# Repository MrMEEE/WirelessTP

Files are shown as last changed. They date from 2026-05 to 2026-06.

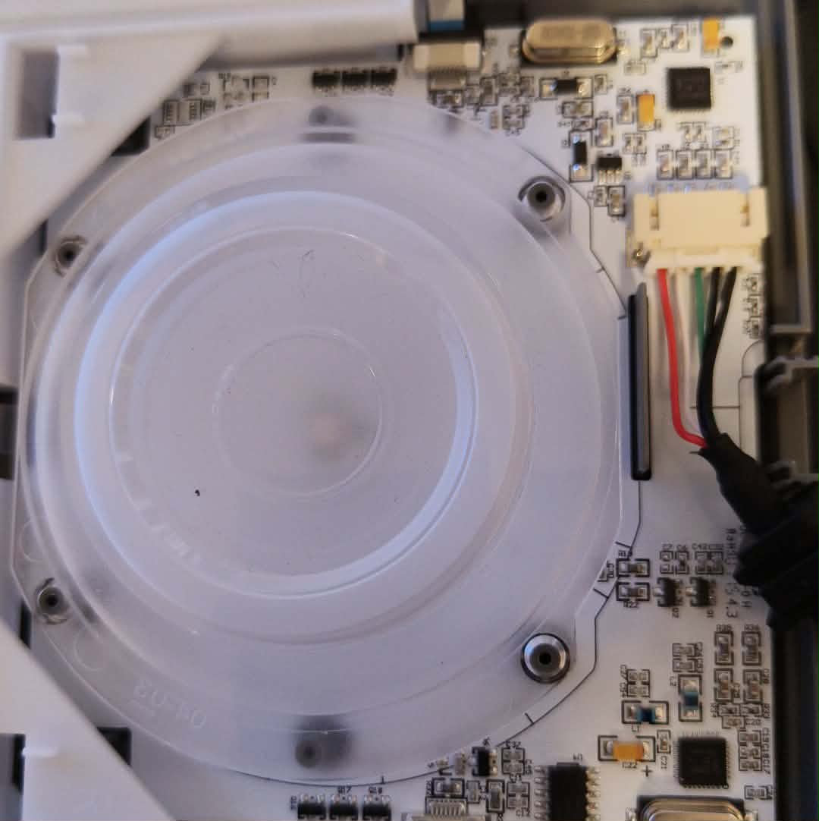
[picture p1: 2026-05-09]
pcb/pics/overview.jpeg

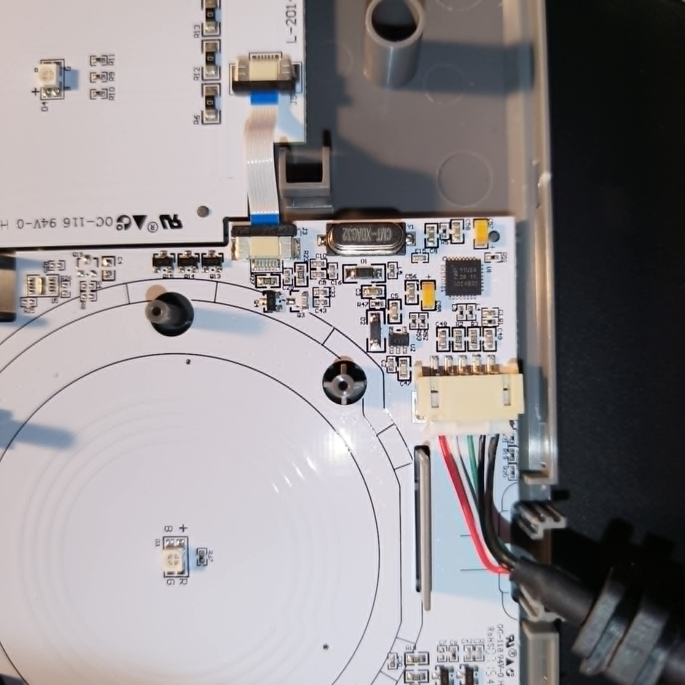
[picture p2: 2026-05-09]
pcb/pics/left.jpeg

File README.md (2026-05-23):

# Wireless LEGO Dimensions Toy Pad Bridge (RP2040 + ESP32 + ESP32)

This repository is a starter for a 3-board architecture:

- Console dongle USB side: Seeed XIAO RP2040
- Console dongle radio side: ESP32 (classic ESP-WROOM-32 is fine)
- Pad side: ESP32

## Why this split

- RP2040 handles strict USB device timing and Toy Pad emulation.
- Console ESP32 hosts a direct open SoftAP and forwards paired pad events over UART to RP2040.
- Pad ESP32 handles tag sensing / virtual events and sends events over Wi-Fi.
- Pad ESP32 includes local setup AP + web portal for first-time provisioning.

This keeps USB timing isolated from Wi-Fi jitter.

## Current status

- Shared packet format (`shared/include/link_protocol.h`) created.
- Console ESP32 starter firmware added (`firmware/console-esp32/src/main.cpp`).
- Console RP2040 starter firmware added (`firmware/console-rp2040/src/main.cpp`).
- Pad ESP32 starter firmware added (`firmware/pad-esp32/src/main.cpp`).
- First protocol document added (`protocol/toypad_link_v1.md`).
- Framed transport with CRC + ACK + heartbeat is wired in all three targets.
- Bring-up checklist added (`docs/bringup-checklist.md`).
- Direct open-AP pairing flow is implemented (no external router required, no serial pair code entry).
- USB protocol findings + RP2040 checklist documented (`docs/usb-protocol-findings-and-rp2040-checklist.md`).
- Xbox 360 donor-auth integration strategy documented (`docs/xbox360-auth-donor-strategy.md`).

## Hardware wiring (console side)

Use UART between console ESP32 and XIAO RP2040:

- ESP32 TX -> RP2040 RX
- ESP32 RX <- RP2040 TX
- ESP32 GND <-> RP2040 GND

Use 3.3 V logic only.

## Build approach

These are framework starter files (not yet board-package complete project files).

For VS Code + PlatformIO IDE, you can now open the repository root directly because it contains a top-level `platformio.ini` that exposes all firmware targets.

You can also open the workspace file at the repo root:

`WirelessTP.code-workspace`

That workspace adds each firmware target as its own VS Code folder so the PlatformIO extension can also show them as separate projects in one window.

You can use either:

1. Arduino IDE per board, or
2. PlatformIO with one env per target.

For the RP2040 there is a single unified environment — profile selection happens at runtime
via a physical toggle switch on the board.

The root-level PlatformIO environments are:

1. `console_esp32`
2. `pad_esp32`
3. `console_rp2040`

## Next milestones

1. Replace RP2040 placeholder with full TinyUSB Toy Pad descriptor + endpoint handlers.
2. Implement deterministic state map for the 3 pad zones and 7 minifig slots.
3. Implement PS-profile USB command parser/checksum path (`0xb0`, `0xc0`, `0xc8`, `0xc2`, `0xc3`).
4. Add NFC reader integration on pad-side ESP32 (or keep virtual events first).
5. Add LED command flow from console game -> RP2040 -> console ESP32 -> pad ESP32.

## Platform support plan

- PlayStation Toy Pad is the primary target for first functional milestone.
- Xbox 360 support is planned next; expect additional compatibility/auth investigation.
- For Xbox 360, start with donor-board auth reuse before attempting chip-level transplant (`docs/xbox360-auth-donor-strategy.md`).
- For jailbroken Xbox 360 setups (JTAG/RGH), an optional modern-controller workaround path is also documented (`docs/xbox360-auth-donor-strategy.md`).
- RP2040 firmware is a single unified build (`console_rp2040`); PS3/Xbox 360 profile is selected at runtime via a physical toggle switch.

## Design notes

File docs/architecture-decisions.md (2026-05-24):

# Architecture Decisions

## Why the console side uses two boards (RP2040 + ESP32)

**Question considered:** Can a single ESP32-S2 Mini replace both the console-rp2040
and console-esp32, eliminating the UART link and the extra board?

**Short answer:** Technically possible, but deliberately not done.

### What each board currently does

| Board | Role |
|---|---|
| XIAO RP2040 | USB HID *device* to game console — emulates the toy pad, handles TEA auth (B1/B3), responds to tag/LED commands |
| Console ESP32 | WiFi AP, web UI, TCP server for pad-esp32, game state (slots/toybox), forwards LP frames to/from RP2040 |

### Why the ESP32-S2 is not a drop-in replacement

1. **USB timing isolation.**
   The RP2040 has no WiFi and a bare-metal FreeRTOS-free loop. Its `loop()` calls
   `TinyUSBDevice.task()` twice per iteration specifically to chain B0 replies within
   one 1 ms USB poll window. On the ESP32-S2, FreeRTOS WiFi tasks (lwIP, beacon
   handling, TCP stack) run on the same or adjacent cores and can introduce multi-ms
   jitter. The B1/B3 TEA auth and the B0 reply timing are sensitive enough that this
   can cause the game console to fail HID enumeration, particularly on real hardware
   (less visible on RPCS3).

2. **RP2040-specific linker tricks cannot be trivially ported.**
   The RP2040 firmware patches the USB configuration descriptor using GCC `--wrap`
   linker symbols (`__wrap_TinyUSB_Device_Init`,
   `__wrap_tud_descriptor_configuration_cb`). These intercept Arduino TinyUSB
   internals at link time. The ESP32-S2 uses the ESP-IDF toolchain; equivalent
   patching would require rewriting these hooks against IDF's `tusb_config` and
   custom descriptor callbacks — a non-trivial porting effort with different testing
   requirements.

3. **`tud_hid_report_complete_cb` chaining.**
   The firmware queues the B0 USB reply inside the HID report-complete callback to
   avoid waiting a full loop cycle. This interrupt-context chaining works reliably on
   RP2040 TinyUSB HAL. Its behaviour on ESP32-S2 TinyUSB (which dispatches USB
   events differently under IDF) has not been validated.

4. **USB serial debug lost.**
   Once the S2's USB OTG port is owned by the game console as a HID device, USB
   serial is gone. All debug output would require a UART adapter on GPIO 43/44.
   On the RP2040 this is a non-issue because the board has a second USB interface
   (XIAO exposes CDC ACM separately from the HID interface).

### Summary

The two-board split exists because the RP2040 provides bare-metal USB timing that
the ESP32-S2 cannot guarantee while simultaneously running a WiFi stack. Merging
them would trade a clean UART interface for a complex, risk-laden port with no clear
gain in the current scope. If timing requirements relax or the protocol is changed
to tolerate jitter, this decision should be revisited.

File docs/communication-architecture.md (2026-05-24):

# WirelessTP Communication Architecture

## System topology

```
Physical Toy Pad (USB HID, VID:PID 0e6f:0241)
        │
        │ USB OTG – host mode (pad-esp32 is host)
        │ 32-byte interrupt IN/OUT reports @ 1ms poll
        ▼
┌────────────────────────┐
│  ESP32-S2 Mini         │  pad-esp32
│  USB host + WiFi STA   │
│  GPIO43=TX  GPIO44=RX  │  (UART for debug only – no LP traffic)
└────────────────────────┘
        │
        │ WiFi – STA joins console softAP
        │ TCP socket, port 25100, LP frames (Link A)
        │ WiFi.setSleep(false), setNoDelay(true)
        ▼
┌────────────────────────┐
│  ESP32 (dual-core)     │  console-esp32
│  WiFi softAP           │  IP 192.168.44.1 (DHCP)
│  GPIO16=RX  GPIO17=TX  │  UART to RP2040 (Serial2, 115 200 baud)
│  USB CDC for debug     │
└────────────────────────┘
        │
        │ UART 115 200 baud, LP frames (Link B)
        │ RP2040 Serial1 D6=TX D7=RX ↔ ESP32 Serial2 GPIO17=TX GPIO16=RX
        ▼
┌────────────────────────┐
│  XIAO RP2040           │  console-rp2040
│  USB HID device        │  emulates Toy Pad
│  (bare-metal loop)     │
└────────────────────────┘
        │
        │ USB HID, VID 0e6f PID 0241 ("LEGO READER V2.10")
        │ 32-byte interrupt IN/OUT reports @ 1ms poll
        ▼
     PS3 / RPCS3 (game)
```

---

## Link A — pad-esp32 ↔ console-esp32 (WiFi TCP)

### Transport

| Property | Value |
|---|---|
| Transport | TCP (not UDP — the original spec was provisional) |
| Console port | 25100 |
| Console IP | 192.168.44.1 (softAP gateway) |
| WiFi AP SSID | `ToyPadConsole-{CHIPID_24LSB_HEX}` |
| AP security | Open (no password) |
| Modem sleep | Disabled: `WiFi.setSleep(false)` on pad |
| Nagle | Disabled: `setNoDelay(true)` on both ends after connect |
| Frame format | LP (see protocol spec) |

### Pad connection state machine

```
CONN_SEARCHING
  ├─ Blink LED yellow (400 ms on/off)
  ├─ TCP connect attempt every kRetryMs=50ms (after disconnect)
  ├─ Send HELLO every kHelloMs=2000ms once connected
  └─► CONN_BLINK_OK   on PAIR_SET received
      └─► CONN_PAIRED  after 3× green blink (≈1200 ms)
CONN_PAIRED
  ├─ Send HELLO every kHeartbeatMs=5000ms (trackAck=true)
  ├─ Re-sync state every kStateSyncMs=1000ms
  ├─ Send pad-dbg (WiFi RSSI/status) every 1000ms
  ├─► CONN_SEARCHING  if !client.connected()  [fast path, no blink]
  └─► CONN_BLINK_FAIL if lastPeerMs > kLostMs=30000ms
CONN_BLINK_FAIL
  ├─ Blink LED red 3×
  └─► CONN_SEARCHING
```

### Pairing sequence (first connection)

```
pad-esp32                            console-esp32
    │                                     │
    │── TCP connect ──────────────────────►│ (accept, setNoDelay, lp_stream_reset)
    │                                     │
    │── HELLO [0xa1]  (trackAck=true) ───►│ isValidPadHello: length=1 → enrollment
    │                                     │ ensureSecret() → generates random 32-bit secret
    │◄── PAIR_SET [secret_u32_le] ────────│
    │                                     │
    │── ACK [pair_set_seq] ───────────────►│
    │  (pending.active=false, paired=true) │
    │  saveSharedSecret()                  │
    │  connState = CONN_BLINK_OK           │
```

### Subsequent connections (known pad)

```
pad-esp32                            console-esp32
    │                                     │
    │── TCP connect ──────────────────────►│
    │── HELLO [0xa1, secret_u32_le] ──────►│ secret matches → padPaired=true
    │◄── PAIR_SET [same secret] ───────────│
    │── ACK ──────────────────────────────►│
```

### Frame flows while paired

| Direction | Frame | Sender action | Receiver action |
|---|---|---|---|
| pad→console | HELLO | every 5 s heartbeat, trackAck=true | ACK, no forward to RP2040 |
| pad→console | TAG_SET | figure placed (physical or virtual), trackAck=true for real events | ACK, forward to RP2040 UART |
| pad→console | TAG_CLEAR | figure removed, trackAck=true | ACK, forward to RP2040 UART |
| pad→console | ACK | response to console LED_CMD | forward to RP2040 UART (harmless; RP2040 does `break`) |
| pad→console | DEBUG (0x40) | WiFi diagnostics every 1 s | print `[pad-dbg]`, **not** forwarded to RP2040 |
| console→pad | LED_CMD | state sync every 1 s (from `lightZones[]`) | ACK, apply colour to physical pad |
| console→pad | PAIR_SET | on pairing | pad saves secret, enters BLINK_OK |

### Pad periodic state sync (every kStateSyncMs=1000ms in CONN_PAIRED)

- Sends TAG_SET for each occupied physical USB zone (zones 0-2 → slots 1-3), trackAck=false
- Sends TAG_SET for each occupied virtual slot (4-7, or 1-7 in no-USB builds), trackAck=false
- Does **not** send TAG_CLEAR for empty slots (avoids queue floods)

### Pad diagnostic frame (LP_MSG_DEBUG)

Sent every 1 second while in CONN_PAIRED:

```
payload: "rssi=-47 wf=3"   (rssi = WiFi.RSSI(), wf = WiFi.status())
```

Console prints as `[pad-dbg] rssi=-47 wf=3` to USB serial. Never forwarded to RP2040.

---

## Link B — console-esp32 ↔ console-rp2040 (UART)

### Transport

| Property | Value |
|---|---|
| Physical | UART, 115 200 baud, 8N1 |
| Console ESP32 | Serial2, GPIO16=RX / GPIO17=TX |
| RP2040 | Serial1, D6=TX / D7=RX |
| Frame format | LP (same protocol as Link A) |

### HELLO heartbeats (bidirectional, independent timers)

| Sender | Payload | Interval | Purpose |
|---|---|---|---|
| console-esp32 → RP2040 | `[0xb1]` | 3 000 ms | console alive signal |
| RP2040 → console-esp32 | `[0x02]` | 4 000 ms | RP2040 alive signal |

Both sides ACK received HELLOs; neither side takes action on missed heartbeats (no timeout logic implemented).

### Frame forwarding rules (console-esp32)

**From pad TCP → RP2040 UART:**

| Frame type | Action |
|---|---|
| HELLO | Drop (pad↔console specific) |
| PAIR_SET | Drop (pad↔console specific) |
| DEBUG (0x40) | Print `[pad-dbg]`, drop — NOT forwarded |
| ACK (0x7F) | Currently forwarded (RP2040 ignores with `case LP_MSG_ACK: break`) |
| TAG_SET, TAG_CLEAR | Re-encode with original seq and write to Serial2 |

**From RP2040 UART → pad TCP:**

| Frame type | Action |
|---|---|
| LED_CMD | Forward to pad TCP via `sendFrameTcp()` |
| HELLO, ACK, DEBUG, all others | Drop |

**ACK sending:**
- All non-ACK frames from pad TCP → ACK sent back to pad TCP
- All non-ACK / non-DEBUG frames from RP2040 UART → ACK sent back to RP2040 UART

### Console state sync (every kStateSyncMs=1000ms)

- TAG_SET to RP2040 UART for each occupied slot in `padSlots[]`
- LED_CMD to pad TCP for each zone in `lightZones[]` (only if `padPaired`)
- `padSlots[]` is **not** cleared when the pad disconnects

### RP2040 toy event queue

- `enqueueToyTagEvent()` queues a 32-byte USB IN packet (placed/removed event)
- `serviceToyInQueue()` drains the queue each loop: peek → `usb_hid.sendReport()` → pop on success
- If `!TinyUSBDevice.mounted()`: entire queue is discarded (`memset(&toyInQueue, 0, ...)`) to prevent stale events accumulating

---

## USB HID protocol (RP2040 ↔ game)

### Descriptors

```
VID:PID      0x0e6f : 0x0241
Manufacturer "PDP LIMITED. "
Product      "LEGO READER V2.10"
Serial       "P.D.P.000000"
Class        HID (vendor-specific usage page 0xff00)
bmAttributes 0x80  (bus powered)
bMaxPower    250   (500 mA)
Report size  32 bytes IN + 32 bytes OUT @ 1 ms poll
bcdHID       0x0100 (patched from TinyUSB default 0x0110)
EP packet    32 bytes IN / 32 bytes OUT (patched from 64)
```

### Host→Pad OUT packets (command)

```
[0] 0x55  magic
[1] len   data bytes following (= 1 + argsLen + 1 for counter+args+checksum)
[2] cmd
[3] counter
[4..4+argsLen-1] args
[4+argsLen] checksum = sum(bytes[0..4+argsLen-1]) & 0xff
[...] zero padding to 32 bytes
```

### Pad→Host IN packets

**Command reply:**
```
[0] 0x55  magic
[1] len   (= 1 + payloadLen)
[2] counter (echoes command counter)
[3..3+payloadLen-1] reply payload
[3+payloadLen] checksum
[...] zeros
```

**Tag event:**
```
[0]  0x56  magic
[1]  0x0b  payload length
[2]  pad   (1=center, 2=left, 3=right)
[3]  0x00  reserved
[4]  figIndex (= slot number 1-7, unique per toy)
[5]  action (0=placed, 1=removed)
[6..12] uid (7 bytes)
[13] checksum
[...] zeros
```

### Commands

| Cmd | Name | Args | Reply payload |
|-----|---|---|---|
| B0 | Init | startup string (observed 16 bytes) | 30-byte capability response |
| B1 | RNG seed | 8 bytes (TEA-encrypted seed+confirmation) | 8 bytes (TEA-encrypted confirmation) |
| B3 | RNG challenge | 8 bytes (TEA-encrypted confirmation) | 8 bytes (TEA-encrypted nextRand+confirmation) |
| C0 | LED immediate | pad(1-3/0=all), r, g, b | empty |
| C2 | LED fade | pad, pulseTime, pulseCount, r, g, b | empty |
| C3 | LED flash | pad, onLen, offLen, pulseCount, r, g, b | empty |
| C6 | LED tri-fade | 3×6 bytes (center, left, right): effect, dur, cnt, r, g, b | empty |
| C8 | LED tri-set | 3×4 bytes (center, left, right): enable, r, g, b | empty |
| D2 | NFC page read | figIndex, startPage → 4 pages (16 bytes) | 0x00 + 16 bytes |
| D3 | NFC page write | figIndex, page, 4 bytes | empty |
| D4 | NFC extended | figIndex, page, ... | varies |

### B1/B3 cryptography

Algorithm matches RPCS3 `Dimensions.cpp`:
- TEA (Tiny Encryption Algorithm), 32 rounds, key = `kCommandKey` (16 bytes hard-coded)
- B1: decrypt challenge → extract seed → init Bob Jenkins PRNG → encrypt confirmation
- B3: decrypt challenge → `rngGetNext()` → encrypt [nextRand LE | conf BE]

### NFC figure data synthesis (D2 replies)

Toy ID is 32 bits: `uid[0..3]` (LE) for physical figures, or the virtual `toyId` for emulated ones.

UID is synthesised as:
```
uid[0..3] = toyId (LE)
uid[4]    = 0xa5
uid[5]    = slot (1-7)   ← makes each slot's UID unique
uid[6]    = toyId ^ 0x5a
```

Pages 0, 1, 2 contain the NTAG213 UID/BCC structure.
Pages 36-37 contain the TEA-encrypted figure identity, using a per-UID figure key
generated by `generateFigureKey()` (matching RPCS3's `generate_figure_key`).

---

## Zone / slot / pad-index convention

Three coordinate systems exist; mappings are defined in firmware:

| Name | Values | Used by |
|---|---|---|
| LP zone | 0=center, 1=left, 2=right | Link A+B LP frames |
| Toy Pad pad-index | 1=center, 2=left, 3=right | USB HID C0/C2/C3 commands |
| Web UI slot | 1-7 | console-esp32 web API, LP TAG_SET/CLEAR payload byte 0 |
| figIndex | 1-7 (= slot) | USB IN tag events, D2 args |

**Slot-to-zone mapping (mirrored in ESP32 and RP2040):**

| Slot | LP zone | Pad-index |
|---|---|---|
| 1 | 1 (left) | 2 |
| 2 | 0 (center) | 1 |
| 3 | 2 (right) | 3 |
| 4 | 1 (left) | 2 |
| 5 | 1 (left) | 2 |
| 6 | 2 (right) | 3 |
| 7 | 2 (right) | 3 |

**Physical USB zone → LP slot (pad-esp32, kZoneToSlot):**

| USB zone (from toypad IN report) | LP zone | Slot |
|---|---|---|
| zone byte 1 (center) | 0 | 2 |
| zone byte 2 (left) | 1 | 1 |
| zone byte 3 (right) | 2 | 3 |

---

## Timing reference

| Constant | Value | Location | Purpose |
|---|---|---|---|
| `kHelloMs` | 2 000 ms | pad-esp32 | HELLO rate while searching |
| `kPairTimeoutMs` | 15 000 ms | pad-esp32 | Give up pairing → blink fail |
| `kHeartbeatMs` | 5 000 ms | pad-esp32 | HELLO rate while paired |
| `kLostMs` | 30 000 ms | pad-esp32 | Console silent → blink fail |
| `kStateSyncMs` | 1 000 ms | pad-esp32 | State re-broadcast interval |
| `kRetryMs` | 50 ms | pad-esp32 | ACK retry interval |
| `kMaxRetries` | 3 | pad-esp32 | Max retry count before drop |
| `kBlinkOnMs/OffMs` | 200/200 ms | pad-esp32 | OK/fail blink timing |
| `kHelloMs` | 3 000 ms | console-esp32 | Console→RP2040 heartbeat rate |
| `kStateSyncMs` | 1 000 ms | console-esp32 | State re-broadcast to RP2040+pad |
| `kHelloMs` | 4 000 ms | console-rp2040 | RP2040→console heartbeat rate |

---

## Reliability model

### Pad-side (Link A outbound)

`sendFrame(type, payload, len, trackAck)`:
- `trackAck=true`: stores frame in `pending`; retried every `kRetryMs=50ms` up to `kMaxRetries=3` from the CONN_PAIRED loop
- `trackAck=false`: fire-and-forget

Frames sent with `trackAck=true`:
- HELLO (heartbeat and searching)
- TAG_SET / TAG_CLEAR from physical USB host events
- TAG_SET / TAG_CLEAR from virtual toy menu

Frames sent `trackAck=false` (fire-and-forget):
- State sync TAG_SET (periodic re-broadcast — retrying is redundant with periodic sync)
- ACK responses
- DEBUG diagnostics

### Console-side (Links A+B inbound)

Every received non-ACK frame generates an ACK back to the sender (pad TCP or RP2040 UART).
The console itself does not have a retry mechanism for outbound frames — it relies on the
periodic state sync to recover from dropped LED_CMDs and TAG_SETs.

---

## Provisioning flow (pad-esp32 first run)

1. Pad has no WiFi credentials in NVS → enters provisioning AP mode
2. Provisioning AP SSID: `ToyPad-Setup`, password: `toypadsetup`
3. DNS catches all hostnames (captive portal pattern)
4. User visits `http://192.168.x.x/` → selects console AP from scan list → submits
5. Credentials saved to NVS (`toypad` namespace, keys `ssid`/`pass`)
6. Reboot → connects to console AP → proceeds to LP pairing

Factory reset: hold BOOT button (GPIO 0) for 3 s → NVS clear + reboot.

---

## Debug interfaces

### pad-esp32

| Interface | Details |
|---|---|
| UART debug | GPIO43=TX / GPIO44=RX, 115 200 baud (USB CDC disabled in USB-host builds) |
| Serial menu | Interactive: press any key; commands `s` / `p <slot>` / `r <slot>` / `f <text>` |
| Web UI | `http://<pad-IP>/` — shows state, console IP, WiFi info |
| LED feedback | Yellow=searching, green blink=paired, red blink=fail |
| pad-dbg relay | WiFi RSSI + status relayed to console as LP_MSG_DEBUG every 1 s |

### console-esp32

| Interface | Details |
|---|---|
| USB CDC serial | 115 200 baud; also prints RP2040 debug (`[lp-debug]`) and pad debug (`[pad-dbg]`) |
| Serial commands | `help`, `pi-console on/off` |
| Web UI | `http://192.168.44.1/` — full toy pad management UI (slots, toybox, LED state, catalog) |
| Log prefixes | `[console-esp32]` events, `[led-rx]` LED commands, `[lp-debug]` RP2040 debug, `[pad-dbg]` pad debug |

### console-rp2040

| Interface | Details |
|---|---|
| UART debug | Serial1 shared with LP link (debug output interleaved with LP frames — console-esp32 filters by CRC) |
| LP_MSG_DEBUG | Sent via UART; console-esp32 prints as `[lp-debug]` |
| Stats | `b0 stats rx=%u q=%u tx=%u` printed every 3 000 ms |

---

## Known issues and active investigations

### TCP disconnect every 3-5 seconds (active)

The pad TCP connection drops reliably every few seconds. WiFi is confirmed stable
(wf=3, rssi=-43 to -47 throughout). The `WiFiClient::connected()` implementation
calls `recv(fd, 0, MSG_DONTWAIT)` and returns false only on RST-level errors
(ECONNRESET/EPIPE/EBADF); FIN does not trigger it. The source of the RST is unknown.

Leading hypotheses (in priority order):
1. lwIP internal socket management on the ESP32-S2 — possibly a timer or PCB limit
2. The console forwarding LP_MSG_ACK frames (from pad's LED_CMD ACKs) to RP2040 UART; RP2040 ignores them but the UART traffic is unnecessary
3. The console's `padClient = incoming` path — replacing a connected client when a new TCP SYN arrives (would print "replacing stale" but may happen silently if `padClient.connected()` transiently returns false)

To diagnose: add errno capture in `tcpSendWire()` and a raw `recv()` probe in
the CONN_PAIRED disconnect handler; relay as first pad-dbg of next connection.

### LP_MSG_ACK forwarding to RP2040 (minor)

The console currently forwards pad ACKs (0x7F) to the RP2040 via UART. The RP2040
handles these with `case LP_MSG_ACK: break;` — safe but wasteful. These 3 frames/second
(one per LED_CMD zone) serve no purpose at the RP2040 level and should be filtered.

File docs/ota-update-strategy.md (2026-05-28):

# OTA / Firmware Update Strategy

## Overview

Three SoCs need to be updated when new firmware is released:

| SoC | Role | Link to console-esp32 |
|---|---|---|
| **console-esp32** | WiFi AP, web UI, TCP broker | — (self) |
| **console-rp2040** | USB HID device to PC/RPCS3 | UART (115200 baud, LP protocol) |
| **pad-esp32** | USB host for physical toypad, WiFi station | WiFi TCP (LP protocol, port 25100) |

The goal is a one-click update flow from the console-esp32 web UI that requires no physical button presses on any board.

---

## Per-Chip Strategy

### 1. console-rp2040 — Custom UART DFU (zero-touch)

The console-esp32 streams the new RP2040 firmware directly over the existing UART connection
using a lightweight chunked DFU protocol. The RP2040 stages the image in the upper half of
its 2 MB flash using arduino-pico's `Updater` class, then reboots to apply it. No button
press, no drag-and-drop — fully automatic.

**Why not BOOTSEL?**
When the RP2040 enters BOOTSEL mode it presents a USB mass-storage drive on the **PC**,
not on the UART-connected console-esp32. The plain ESP32 has no USB host hardware, so it
cannot write to that drive. BOOTSEL is not useful for an automated update flow.

**Why arduino-pico `Updater`?**
The EarlePhilhower arduino-pico fork includes an `Updater` class that writes incoming bytes
to a staging area in the upper half of flash. Only when `Updater.end()` is called and the
full-image CRC32 matches does it mark the staged firmware as the next boot target. If power
is cut at any point before the commit, the current firmware is untouched — no brick risk.

**Trigger path:**
1. Console-esp32 web UI receives `POST /ota/upload-rp2040`; binary stored in LittleFS.
2. Console-esp32 sends `LP_MSG_OTA_BEGIN` (0x50) over UART, payload `[size LE4][crc32 LE4]`.
3. RP2040 calls `Updater.begin(size)`, replies `LP_MSG_ACK`.
4. Console-esp32 streams firmware data as DFU chunks (see UART DFU Protocol section).
5. Console-esp32 sends `LP_MSG_OTA_COMMIT` (0x51) with empty payload.
6. RP2040 calls `Updater.end()`, verifies CRC32. On success: `rp2040.restart()`.
7. Console-esp32 waits for UART HELLO within ~5 s to confirm the new firmware is running.

### 2. pad-esp32 — OTA fetch over WiFi

Since the pad-esp32 connects to the console-esp32 WiFi AP, it can HTTP-GET its own firmware
from the console-esp32 without any external server.

**Trigger path:**
1. Console-esp32 web UI receives `POST /ota/upload-pad`; binary stored in LittleFS.
2. Console-esp32 sends `LP_MSG_OTA_BEGIN` (0x50) over TCP with payload `[size LE4][crc32 LE4]`.
3. Pad-esp32 calls `httpUpdate.update("http://192.168.4.1/ota/pad-esp32.bin")`.
4. Pad-esp32 self-flashes and reboots. It reconnects automatically once done.

**Notes:**
- The pad-esp32 already has OTA partition support (ESP32-S2 with 4MB flash); the partition
  table needs to be confirmed / updated to include OTA0 + OTA1 + LittleFS.
- Alternatively, the console-esp32 can stream the binary on-demand (the pad-esp32 opens an
  HTTP connection and the console-esp32 serves the bytes as they are uploaded from the
  browser), avoiding the need to store the full binary in LittleFS.

### 3. console-esp32 — Self OTA (applied last)

Standard Arduino ESP32 OTA using the `Update` library.

**Trigger path:**
1. Web UI receives `POST /ota/upload-console` with the new firmware binary.
2. Console-esp32 pipes it through `Update.write()` into the OTA1 partition.
3. On completion, `Update.end()` marks the OTA1 partition as the next boot target.
4. Console-esp32 calls `ESP.restart()` and comes back on the new firmware.

**Must run last** — once it restarts, it can no longer coordinate the other chips.

---

## UART DFU Protocol (console-esp32 → console-rp2040)

LP frames handle signalling. A separate lightweight chunked format carries the firmware
bytes, because `LP_MAX_PAYLOAD = 64` would make a full-image transfer impractically slow.

### Signalling (LP frames)

| Opcode | Direction | Payload | Meaning |
|---|---|---|---|
| `LP_MSG_OTA_BEGIN`  0x50 | ESP32 → RP2040 (UART) | `[size LE4][crc32 LE4]` | Start DFU; RP2040 calls `Updater.begin(size)`, replies ACK |
| `LP_MSG_OTA_COMMIT` 0x51 | ESP32 → RP2040 (UART) | _(empty)_ | All chunks sent; RP2040 calls `Updater.end()`, verifies CRC32, reboots |
| `LP_MSG_OTA_BEGIN`  0x50 | ESP32 → pad-esp32 (TCP) | `[size LE4][crc32 LE4]` | Trigger pad-esp32 HTTP OTA fetch |

### Data chunks (raw, over same UART — outside LP framing)

After the RP2040 ACKs `LP_MSG_OTA_BEGIN`, the UART switches to raw DFU chunk mode.
Each chunk:

```
Offset  Size  Field
──────  ────  ──────────────────────────────────────────────────────
0       2     Magic: 0xDF 0xC0
2       4     Byte offset in firmware image (LE uint32)
6       2     Chunk data length in bytes, max 1024 (LE uint16)
8       N     Firmware bytes  (N = length field)
8+N     2     CRC16-CCITT of the N data bytes (LE uint16)
```

RP2040 responds to each chunk with one byte:
- `0x06` — ACK (chunk accepted, passed to `Updater.write()`)
- `0x15` — NAK (CRC mismatch; console-esp32 retransmits the same chunk)

The console-esp32 waits for ACK/NAK before sending the next chunk (up to 3 retries per
chunk, then aborts). After all chunks are ACKed it sends `LP_MSG_OTA_COMMIT`.

### Timeouts

- **RP2040**: if no chunk arrives within 10 s after ACKing `LP_MSG_OTA_BEGIN`, the DFU
  session is silently aborted. `Updater` is not committed so current firmware is safe.
- **Console-esp32**: 3 s per-chunk ACK timeout, 3 retries, then abort.

### Flash layout — XIAO RP2040 (2 MB)

The arduino-pico `Updater` stores the incoming image in the upper half of flash and only
marks it for boot on a successful `Updater.end()` — safe against mid-transfer power loss.

```
0x10000000  ┌───────────────────────────────┐
            │  boot2 (256 B)                │
            │  running firmware             │  ≤ 1 MB
0x10100000  ├───────────────────────────────┤
            │  Updater staging area         │  ≤ 1 MB
            │  (new image written here)     │
0x10200000  └───────────────────────────────┘
```

---

## Update Sequence

```
User uploads firmware package to web UI
          │
          ▼
[1] POST /ota/upload-rp2040  (binary stored in LittleFS)
    ESP32 → (UART LP_MSG_OTA_BEGIN[size,crc32]) → RP2040
    RP2040: Updater.begin(size) → ACK
    ESP32 streams DFU chunks (1024 B each, CRC16 per chunk)
    ESP32 → (UART LP_MSG_OTA_COMMIT) → RP2040
    RP2040: Updater.end(), verify CRC32 → rp2040.restart()
          │
          ▼  (~5 s — RP2040 reboots with new firmware, no user action)
[2] RP2040 UART HELLO received → confirmed
          │
          ▼
[3] POST /ota/upload-pad  (binary stored in LittleFS)
    ESP32 → (TCP LP_MSG_OTA_BEGIN[size,crc32]) → pad-esp32
    pad-esp32: httpUpdate("http://192.168.4.1/ota/pad-esp32.bin") → reboots
    pad-esp32 reconnects → confirmed
          │
          ▼
[4] POST /ota/upload-console
    console-esp32 applies OTA via Update library → ESP.restart()
    Done.
```

---

## Required Changes

### shared/include/link_protocol.h
Add two new LP message types:
```c
LP_MSG_OTA_BEGIN  = 0x50,  // ESP32→RP2040 (UART): begin DFU, payload=[size LE4][crc32 LE4]
                           // ESP32→pad-esp32 (TCP): trigger HTTP OTA fetch
LP_MSG_OTA_COMMIT = 0x51,  // ESP32→RP2040 (UART): all chunks sent, commit and reboot
```

### firmware/console-rp2040/src/main.cpp
- Handle `LP_MSG_OTA_BEGIN`: call `Updater.begin(size)`, reply ACK, switch to chunk-receive loop.
- Receive raw DFU chunks: `Updater.write()` per chunk, respond `0x06`/`0x15` per chunk.
- Handle `LP_MSG_OTA_COMMIT`: call `Updater.end()`, verify CRC32, call `rp2040.restart()`.
- 10 s idle timeout to abort safely if ESP32 disconnects mid-transfer.
- Enable OTA staging in `platformio.ini` (sufficient flash reserved for upper-half staging).

### firmware/pad-esp32/src/main.cpp
- Handle `LP_MSG_OTA_BEGIN` (TCP): call `httpUpdate.update("http://192.168.4.1/ota/pad-esp32.bin")`.
- Ensure OTA partitions are present in the partition CSV.

### firmware/console-esp32/platformio.ini + partition table
- Custom partition CSV: OTA0 + OTA1 (≥ 1.5 MB each) + LittleFS (~960 KB).
- Add `LittleFS` for binary storage and `Update` library for self-flash.
- Add web UI routes: `POST /ota/upload-rp2040`, `POST /ota/upload-pad`,
  `POST /ota/upload-console`, `GET /ota/pad-esp32.bin`.

### firmware/console-esp32/src/main.cpp
- `POST /ota/upload-rp2040`: save to LittleFS, send `LP_MSG_OTA_BEGIN` over UART, stream
  DFU chunks (1024 B + CRC16 each), send `LP_MSG_OTA_COMMIT`, wait for UART HELLO.
- `GET /ota/pad-esp32.bin`: serve binary from LittleFS.
- `POST /ota/upload-pad`: save to LittleFS, send `LP_MSG_OTA_BEGIN` over TCP.
- `POST /ota/upload-console`: stream through `Update` library, `ESP.restart()`.

---

## Flash Layout

### console-esp32 (4 MB)

Current app binary: ~838 KB. A custom partition table is needed to fit two app partitions
+ LittleFS large enough to hold the pad-esp32 binary:

| Name | Type | SubType | Size | Notes |
|---|---|---|---|---|
| nvs | data | nvs | 20 KB | |
| otadata | data | ota | 8 KB | |
| app0 | app  | ota_0 | 1.5 MB  | Running firmware |
| app1 | app  | ota_1 | 1.5 MB  | OTA staging target |
| littlefs  | data | spiffs  | ~960 KB | pad-esp32.bin + rp2040 bin |

Total: ≈ 4 MB. The pad binary (838 KB) fits in 960 KB LittleFS with ~120 KB spare.
Streaming the pad binary on-the-fly (no LittleFS storage) removes this constraint
entirely but requires the pad to be connected during the upload step.

### console-rp2040 (XIAO RP2040, 2 MB)

See the flash layout diagram in the UART DFU Protocol section above. arduino-pico's
`Updater` handles the staging area automatically; no manual partition table required.

---

## Open Questions / Decisions Needed

1. **Bundle vs. separate uploads** — Single firmware package (zip or custom container
   unpacked by console-esp32) or three separate upload buttons? A bundle is more
   user-friendly but adds parsing complexity on the constrained ESP32.

2. **Store or stream pad binary** — Storing in LittleFS allows retry and decouples upload
   timing from the pad being online, but requires the tight partition layout above.
   Streaming avoids storage but means the pad must be connected during upload.

3. **UART baud rate during DFU** — 115200 baud gives ~11 KB/s. The RP2040 binary is small
   so this is fine. If we ever route pad-esp32 updates through UART (unlikely) we'd want
   higher baud; 921600 gives ~90 KB/s if the hardware traces support it.

4. **Rollback** — The ESP32 Arduino `Update` library supports automatic rollback if
   `Update.end(true)` is used with `esp_ota_mark_app_valid_cancel_rollback()` called on
   successful boot. Worth wiring up for the console-esp32 self-update.

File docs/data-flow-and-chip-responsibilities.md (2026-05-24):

# Data Flow and Chip Responsibilities

## System Overview

```
Physical Toypad ──USB HID──► pad-esp32 ──WiFi TCP──► console-esp32 ──UART──► console-rp2040 ──USB HID──► Game (RPCS3/PS3)
                 ◄──USB HID──             ◄──WiFi TCP──               ◄──UART──               ◄──USB HID──
                  (LED cmds)               (LED cmds)                   (LED cmds)
```

---

## 1. Physical Toypad → pad-esp32 (USB HID IN, 32-byte reports)

### Tag event (toy placed or removed)

| Byte | Value | Description |
|---|---|---|
| 0 | `0x56` | Magic (portal → host event) |
| 1 | `0x0b` | Payload length |
| 2 | 1–3 | Physical pad zone: 1=center, 2=left, 3=right |
| 3 | `0x00` | Reserved |
| 4 | `0x00` | Reserved |
| 5 | 0 / 1 | Action: 0=placed, 1=removed |
| 6–12 | — | NFC UID (7 bytes, NTAG213, BCC0 excluded) |
| 13 | — | Checksum (sum of bytes 0–12, mod 256) |

Pad-esp32 converts `padZone` (1-3) to `lpZone` (0-2): `lpZone = padZone - 1`.

### D2 NFC page-read reply (success)

| Byte | Value | Description |
|---|---|---|
| 0 | `0x55` | Magic |
| 1 | `0x12` | Reply type |
| 2 | — | Counter (echoed from the D2 request) |
| 3 | `0x00` | Status: 0 = success |
| 4–19 | — | 16 bytes of NFC data (4 pages starting from the requested page) |

### D2 NFC page-read reply (error)

Byte 3 is non-zero, or length field is unexpected. Pad-esp32 aborts and
retries the slot (up to 3 attempts on the hint zone, once on fallback zones).

---

## 2. pad-esp32 → Physical Toypad (USB HID OUT, 32-byte reports)

All out-reports: `[0x55, len, cmd, counter, args..., checksum, 0x00 padding]`.
Checksum = sum of bytes [0..(len+1)], mod 256.

| Command | Bytes | Description |
|---|---|---|
| B0 wake | `55 0f b0 01 "(c) LEGO 2014" checksum` | Sent on device open to initialise pad |
| B1 seed | `55 0a b1 ctr TEA(seed_LE\|conf_BE)[8] checksum` | Seeds pad RNG |
| B3 challenge | `55 0a b3 ctr TEA(conf_BE\|00000000)[8] checksum` | Completes auth |
| C0 LED | `55 06 c0 ctr padIdx r g b checksum` | padIdx: 0=all, 1=center, 2=left, 3=right |
| D2 read | `55 04 d2 ctr figIdx page checksum` | figIdx: 0=center, 1=left, 2=right; page: NFC page number |

---

## 3. pad-esp32 NFC Figure Key Derivation

Used only by pad-esp32 to read the LEGO character/vehicle ID from physical NFC
page 36.  The algorithm is a port of RPCS3 `Dimensions.cpp`.

**`padFigScramble(uid[7], count)`**
1. Build a 24-byte buffer: `uid[7] ++ kCharConstant[17]`.
2. Set `buf[count * 4 - 1] = 0xaa` — the Ellerbach constant used by the physical
   toypad's firmware to scramble factory-written character tags.
   (RPCS3's emulator uses `^= count` instead; vehicles written by the game use
   that algorithm — see the vehicle note below.)
3. Run `dimensions_randomize()` over the buffer in 4-byte little-endian chunks.

**`padGenerateFigureKey(uid[7], key[16])`**
1. Compute `s3..s6 = padFigScramble(uid, 3..6)`.
2. Store each `u32` as **big-endian** into 4 consecutive key bytes.
   The physical toy's NFC was encrypted with big-endian key words (matching
   RPCS3's `write_to_ptr<be_t<u32>>`).  The TEA decrypt then reads those bytes
   back as little-endian, which is equivalent to `byteswap(sN)` as the TEA key
   word — exactly what the physical toy was encrypted with.

**`padTeaDecryptWithKey(in[8], out[8], key[16])`**
Standard 32-round Tiny Encryption Algorithm (TEA) decrypt, reading key words as
little-endian from the 16-byte key buffer.

**Validation:** `readPhysicalToyId` decrypts NFC page 36 → 8 bytes → two u32
words `id0` and `id1`.  The encoding stores the character ID twice; `id0 == id1`
confirms the correct key was used and the correct reader slot was queried.

### Vehicle note

Vehicles start blank and are programmed by the game console at runtime.  The game
writes NFC pages using the RPCS3 scramble variant (`^= count`, not `= 0xaa`).
Reading vehicle IDs from physical tags therefore requires a different scramble
constant.  This is tracked as a separate work item.

---

## 4. pad-esp32 → console-esp32 (WiFi TCP, LP framing)

LP frame: `[L D 01 type seq len] [payload…] [crc16 2 bytes]`

| Message | Type | Payload | Meaning |
|---|---|---|---|
| `TAG_SET` | `0x10` | `[slot(1-7), zone(0-2), toyId[4 LE]]` | Physical toy placed; includes resolved LEGO character ID |
| `TAG_CLEAR` | `0x11` | `[slot]` | Physical toy removed |
| `HELLO` | `0x01` | `[0xa1, secret[4 LE]?]` | Heartbeat / pairing |
| `ACK` | `0x7f` | `[echoed-seq]` | Acknowledged a reliable frame |
| `DEBUG` | `0x40` | ASCII string | D2 result log (e.g. `d2:ok:0001 fi=0`) |

Zone encoding: `0` = center, `1` = left, `2` = right (LP convention throughout).

---

## 5. console-esp32 Responsibilities

- Runs a **TCP server** on port 25100, accepts the pad-esp32 connection.
- Runs a **WiFi AP** (or STA) so the pad-esp32 can reach it.
- Maintains **`padSlots[7]`**: slot occupancy, toyId, display label, type.
- Maintains **`lightZones[3]`**: per-zone LED RGB state.
- Forwards `TAG_SET` / `TAG_CLEAR` and `LED_CMD` between pad-esp32 (TCP) and
  console-rp2040 (UART) in both directions.
- Serves the **main web UI** on port 80 — shows game slots, toybox, LED colours.

---

## 6. console-esp32 → console-rp2040 (UART 115200, LP framing)

Same LP framing as TCP.  Messages forwarded:

| Message | Direction | Payload |
|---|---|---|
| `TAG_SET` | ESP32 → RP2040 | `[slot, zone, toyId[4 LE]]` |
| `TAG_CLEAR` | ESP32 → RP2040 | `[slot]` |
| `LED_CMD` | RP2040 → ESP32 | `[zone(0-2 or 0xff=all), r, g, b]` |
| `HELLO` | Both | Heartbeat |

---

## 7. console-rp2040 Responsibilities

- Acts as a **USB HID device** to the game console, presenting as the LEGO
  Dimensions Toy Pad (VID `0x0e6f`, PID `0x0241`, "LEGO READER V2.10").
- Maintains **`ToyPadState`**: per-zone LED colour, per-slot UID and toyId.
- On `TAG_SET`: stores `toyId`, builds a synthetic 7-byte NFC UID from it, and
  encrypts `toyId` (twice, as a TEA pair) into a synthetic NFC block using
  `generateFigureKey` (RPCS3 algorithm: `^= count`, BE key storage).
- On game `B0`: queues a hardcoded startup reply matching a real pad's response.
- On game `B1` / `B3`: performs TEA auth using `kCommandKey`.
- On game `D2` (block-read): serves synthetic NFC data for the requested slot and
  page range, applying the D3 write cache for vehicle upgrade pages.
- On game `D3` (block-write): stores written pages in the write cache.
- On game `C0` (LED set): extracts RGB, updates LED state, sends `LED_CMD` over
  UART to console-esp32.

**Key difference from pad-esp32:** rp2040 `figureScramble` uses `buf[count*4-1]
^= count` (RPCS3 algorithm), while pad-esp32 `padFigScramble` uses `= 0xaa`
(Ellerbach / physical-toy algorithm).  Both store the key as big-endian.  The
rp2040 path is self-consistent with RPCS3: the game encrypts with `^= count` +
BE, and the rp2040 emulates the same.

---

## 8. console-rp2040 → Game (USB HID IN, 32-byte reports)

### Tag event

| Byte | Value | Description |
|---|---|---|
| 0 | `0x56` | Magic |
| 1 | `0x0b` | Payload length |
| 2 | 1–3 | Pad zone in toy-pad convention: 1=center, 2=left, 3=right |
| 3 | `0x00` | Reserved |
| 4 | — | Figure index = slot number (1-7, stable per toy) |
| 5 | 0 / 1 | Action: 0=placed, 1=removed |
| 6–12 | — | Synthetic NFC UID (7 bytes, derived from toyId and slot) |
| 13 | — | Checksum |

`lpZone` (0-2) → toypad convention (1-3): `lpZoneToToyZone(z) = z + 1`.

### D2 NFC page-read reply

Same format as physical pad reply (bytes 0-19), but data is synthetic —
generated by `generateFigureKey` + TEA encrypt using the RPCS3 algorithm.

---

## 9. Webui Toy Name Resolution

The webui on console-esp32 (and pad-esp32) uses the compiled-in catalog
(`ld_catalog_data.h`) to resolve `toyId` → display name:

```js
function toyInfo(id) {
  return catalog[id] || { name: 'Toy ' + id + ' 0x' + id.toString(16), world: '?' };
}
```

If `readPhysicalToyId` returns the wrong `toyId` (e.g. 257 instead of 1 for
Batman), `catalog[257]` is undefined and the webui shows `"Toy 257 0x101"`.
The root cause was a key-endianness bug in `padGenerateFigureKey` (fixed —
see `architecture-decisions.md` for details).

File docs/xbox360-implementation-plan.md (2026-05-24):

# Xbox 360 Implementation Plan

This document captures the full analysis for adding Xbox 360 support to WirelessTP, covering
protocol differences, authentication, USB descriptor changes, report framing, the physical
mode-switch design, and implementation order.

No firmware changes are made yet. This document serves as the design record.

---

## 1. LEGO Dimensions Xbox 360 Protocol Findings

### No LEGO Dimensions–specific Xbox 360 documentation exists

An exhaustive search of public sources (GitHub, wiki.tresni, marijnkneppers.dev, brandonw.net,
portal_of_flipper, and related projects) produced no LEGO Dimensions–specific Xbox 360 USB
protocol documentation.

### Command layer is identical across all platforms and games

The toys-to-life command layer used by LEGO Dimensions is the same as Skylanders across PS3,
Xbox 360, Wii, and PC:

| Command | Byte 0 | Purpose |
|---|---|---|
| Ready | `R` / `0x52` | Portal identity query |
| Activate | `A` / `0x41` | Activate/deactivate |
| Status  | `S` / `0x53` | Figure presence poll |
| Color | `C` / `0x43` | LED RGB set |
| Query | `Q` / `0x51` | NFC block read |
| Write | `W` / `0x57` | NFC block write |
| Light | `L` / `0x4C` | Zone lighting (LEGO Dimensions) |
| Join | `J` / `0x4A` | Join confirmation |
| Minifig | `M` / `0x4D` | Minifig metadata |
| B0/B1/B3/C0/D2 | — | Portal auth & NFC ops (LEGO-specific) |

All reports are 32 bytes, zero-padded. Report 0 byte is the command letter (echo back in responses).

### Conclusion for this project

The Xbox 360 LEGO Dimensions portal almost certainly uses identical report payloads to the PS3
version. The only differences are:

1. The USB device class/descriptor set (Xbox 360 uses a custom vendor class, not HID)
2. XSM3 hardware security authentication on the USB connection
3. The framing wrapper on interrupt IN/OUT reports

Per decision during analysis: **presume no protocol difference between platforms.**

### Unknown: Xbox 360 LEGO Dimensions VID:PID

| Console | VID | PID | Source |
|---|---|---|---|
| PS3 | 0x0E6F | 0x0241 | Confirmed via USB capture (this project) |
| Xbox 360 | 0x0E6F | **?** | Not documented publicly |

The manufacturer is PDP Limited (VID 0x0E6F) for both consoles. The Xbox 360 PID is unknown
and would require a USB capture from real Xbox 360 LEGO Dimensions hardware to confirm.
As a starting point, the same VID can be used while the PID is left as a placeholder.

Reference: The Skylanders Xbox 360 portal uses VID 0x1430, PID 0x1F17, which is a
*different manufacturer* — not applicable to LEGO Dimensions.

---

## 2. Xbox 360 USB Architecture

### PS3 (current)

```
bDeviceClass = 0x00  (per-interface)
bNumInterfaces = 1

Interface 0: HID, bInterfaceClass=0x03
  EP 1 IN  (interrupt, 32 bytes, 1ms)
  EP 1 OUT (interrupt, 32 bytes, 1ms)
```

USB strings:
- Manufacturer: `PDP LIMITED. `
- Product: `LEGO READER V2.10`
- Serial: `P.D.P.000000`

### Xbox 360

Xbox 360 uses a custom vendor class (not HID). The descriptor structure follows the standard
Xbox 360 wired controller pattern, which must be replicated exactly for the console to communicate:

```
bDeviceClass = 0xFF  (vendor-specific)
bNumInterfaces = 4

Interface 0: Gamepad/data  (bInterfaceSubClass=0x5D, bInterfaceProtocol=0x01)
  EP 1 IN  (interrupt, up to 32 bytes)
  EP 2 OUT (interrupt, up to 32 bytes)

Interface 1: Headset audio IN  (bInterfaceSubClass=0x5D, bInterfaceProtocol=0x03)
  (minimal/stub for portal use)

Interface 2: Headset audio OUT  (bInterfaceSubClass=0x5D, bInterfaceProtocol=0x02)
  (minimal/stub for portal use)

Interface 3: XSM3 Security  (bInterfaceSubClass=0x5D, bInterfaceProtocol=0x13)
  No endpoints — auth via control requests only
  String descriptor 4: "Xbox Security Method 3, Version 1.00, 2005 Microsoft Corporation. All rights reserved."
```

The string descriptor on interface 3 is critical. Without it, the Xbox 360 console will not
attempt further communication.

Reference: [brandonw.net/360bridge/doc.php](https://www.brandonw.net/360bridge/doc.php),
[portal_of_flipper](https://github.com/sanjay900/portal_of_flipper)

---

## 3. XSM3 Security Authentication

### Overview

Xbox 360 uses a hardware security mechanism (Xbox Security Method 3 / XSM3) that prevents
unauthorized USB peripherals. The console issues two sequential challenges; the device must
respond correctly or all communication stops.

### Library

**libxsm3** by InvoxiPlayGames: [github.com/InvoxiPlayGames/libxsm3](https://github.com/InvoxiPlayGames/libxsm3)

**MrMEEE's RP2040 fork**: [github.com/MrMEEE/libxsm3](https://github.com/MrMEEE/libxsm3)
- License: LGPL-2.1
- Pure C implementation
- Adds RP2040/Pico embedded platform fixes (no heap dependency on init path)
- Implements DES + SHA-1 + Microsoft's PARVE algorithm using retail keys embedded in the library
- Tested working on RP2040

### Control request sequence (interface 3)

All requests are standard USB device/interface control transfers on interface 3:

| bRequest | Direction | Operation |
|---|---|---|
| `0x81` | IN  | Get static ID data → call `xsm3_id_data_ms_controller()` |
| `0x82` | OUT | Receive challenge init → call `xsm3_do_challenge_init()` |
| `0x83` | IN  | Send challenge response → call `xsm3_challenge_response()` |
| `0x84` | — | Challenge-success notification (no action needed) |
| `0x86` | IN  | Get status → return `[0x01, 0x00]` (busy) or `[0x02, 0x00]` (ready) |
| `0x87` | OUT | Receive challenge verify → call `xsm3_do_challenge_verify()` |

### Initialization

```c
xsm3_state_t xsm3;
xsm3_set_vid_pid(&xsm3, USB_VID, USB_PID);   // use portal's actual VID:PID
xsm3_initialise_state(&xsm3);
```

### Key category

The libxsm3 key set used is `xsm3_id_data_ms_controller` (wired controller keys). This is
the same key category used by portal_of_flipper for the Skylanders portal on Xbox 360, and
it works in practice. LEGO Dimensions Xbox 360 portal should use the same category.

### Integration point

XSM3 runs entirely on the console-rp2040. No changes to pad-esp32, console-esp32, or the
link protocol are needed for auth. The RP2040 handles all XSM3 control requests locally.

---

## 4. Report Framing Differences

### PS3

Raw 32-byte HID interrupt transfers:
```
OUT [00..31]: command payload (A/R/S/Q/W/L etc.)
IN  [00..31]: response payload
```

### Xbox 360

Reports use a 2-byte header prefix on the Xbox 360 vendor class:
```
OUT: [0x00, 0x14, payload bytes 2..31]   (host → portal)
IN:  [0x0B, 0x14, payload bytes 2..31]   (portal → host)
```

The first byte identifies the report type:
- `0x00` / `0x0B` = data (portal command/response)
- `0x0B, 0x17` = audio (ADPCM; not used by LEGO Dimensions portal)

**The 32-byte command payload itself is unchanged** — only the 2-byte framing prefix differs.
The gating of this framing is the primary firmware change needed in console-rp2040 for Xbox 360
report handling.

---

## 5. Audio / Headset

Xbox 360 controllers expose headset interfaces (interfaces 1 and 2). For a portal device:
- Audio is never used by the game
- The interfaces must exist in the descriptor to satisfy the console enumeration
- No audio data needs to be handled; stub/minimal descriptors suffice

LEGO Dimensions has no audio output through the portal on any platform.

---

## 6. Chips Affected by Xbox 360 Support

| Component | Change needed |
|---|---|
| console-rp2040 | Yes — USB descriptor, XSM3 auth, report framing, mode select GPIO |
| console-esp32 | No |
| pad-esp32 | No |
| Link protocol (LP) | No |
| Physical Toy Pad | No |

All Xbox 360-specific logic is isolated to console-rp2040.

---

## 7. Physical Mode Switch on console-rp2040 (XIAO RP2040)

### Motivation

A physical toggle switch allows selecting PS3 or Xbox 360 mode at any time without reflashing.
This is useful for development (quickly testing both paths) and for end-user builds where
the same hardware should support both consoles. The switch is read at boot and also monitored
continuously at runtime — a change triggers a USB re-enumeration with the new profile.

### XIAO RP2040 Pin Availability

| Pin | Function | Available? |
|-----|---|---|
| D0  | GPIO / ADC | **Yes — use for switch** |
| D1  | GPIO / ADC | **Yes — use for status LED** |
| D2  | GPIO / ADC | Yes |
| D3  | GPIO / ADC | Yes |
| D4  | I2C SDA | Yes (if I2C not used) |
| D5  | I2C SCL | Yes (if I2C not used) |
| D6  | UART TX → console ESP32 | **In use** |
| D7  | UART RX ← console ESP32 | **In use** |
| D8  | SPI SCK | Yes (if SPI not used) |
| D9  | SPI MISO | Yes (if SPI not used) |
| D10 | SPI MOSI | Yes (if SPI not used) |
| 11  | NeoPixel enable | Reserved (on-board LED) |
| 12  | NeoPixel data | Reserved (on-board LED) |

**Recommended pins: D0** for the switch, **D1** for the status LED.

### Hardware Design

```
XIAO RP2040 D0 ──── [SPDT or SPST toggle switch] ──── GND

XIAO RP2040 D1 ──── [330 Ω resistor] ──── [LED anode]
                                           [LED cathode] ──── GND
```

Switch:
- Enable internal pull-up (`INPUT_PULLUP`) in firmware
- Switch **open** → pin reads HIGH → PS3 mode
- Switch **closed** (to GND) → pin reads LOW → Xbox 360 mode
- No external resistor needed (internal pull-up is sufficient)

Status LED:
- **ON** (D1 HIGH) → PS3 mode active
- **OFF** (D1 LOW) → Xbox 360 mode active
- 330 Ω current-limiting resistor (3.3 V drive, ~5–10 mA through a standard LED)
- Any colour works; blue pairs visually with the NeoPixel PS indicator

An SPDT center-off or a standard SPST toggle both work. A slide switch on the PCB or a panel
switch in the enclosure are both viable.

### Firmware Behaviour

**At boot (`setup()`):**
1. `pinMode(D0, INPUT_PULLUP)` — switch input.
2. `pinMode(D1, OUTPUT)` — status LED output.
3. Read D0 before USB initialisation.
4. Select `PROFILE_PLAYSTATION` (HIGH) or `PROFILE_XBOX360` (LOW).
5. Write D1: `HIGH` for PS3, `LOW` for Xbox 360.
6. Load the appropriate USB descriptor set and auth handler.
7. Record the initial pin state as `lastSwitchState`.

**At runtime (`loop()`):**
1. Poll D0 on every iteration (no interrupt needed — the loop is fast enough).
2. Debounce: require the new state to be stable for ~50 ms before acting.
3. If the debounced state differs from `lastSwitchState`:
   a. Update `lastSwitchState` and the active profile.
   b. Call `TinyUSBDevice.detach()` to disconnect from the host.
   c. Tear down any XSM3 state (re-call `xsm3_initialise_state()` if switching to/from Xbox).
   d. Wait ~500 ms (host de-enumeration time).
   e. Re-configure the USB descriptors for the new profile.
   f. Call `TinyUSBDevice.attach()` to re-enumerate with the new identity.
4. Write D1: `HIGH` (PS3) or `LOW` (Xbox 360).
5. Update the NeoPixel to the new profile colour.

The host treats this as a physical unplug/replug. The game will need to re-detect the portal,
which is the same behaviour as physically removing and reconnecting it.

### LED Mode Indication (NeoPixel)

The XIAO RP2040 has a WS2812 NeoPixel (data on pin 12, power enable on pin 11).
This can indicate the active profile:

| Profile | NeoPixel colour |
|---|---|
| PS3 | Blue (PlayStation brand colour) |
| Xbox 360 | Green (Xbox brand colour) |

Keep the NeoPixel lit continuously to show the active mode. During the USB detach/reattach
transition, briefly flash the new colour to signal the switch. This is optional and can be
skipped on first implementation.

---

## 8. Implementation Order (when ready to code)

1. **Add libxsm3 as a submodule** under `firmware/console-rp2040/lib/libxsm3/`
   - Use MrMEEE's RP2040 fork: `github.com/MrMEEE/libxsm3`
   - Add to `platformio.ini` `lib_deps` in the `console_rp2040` environment

2. **Add Xbox 360 USB descriptor block** in `console-rp2040/src/main.cpp`
   - 4-interface vendor-class descriptor, gated on `TOY_PROFILE_XBOX360`
   - Confirm Xbox 360 LEGO Dimensions VID:PID (hardware capture or community source)

3. **Add XSM3 control-request handler** for interface 3
   - Handle `0x81 / 0x82 / 0x83 / 0x84 / 0x86 / 0x87` on the security interface
   - Call `xsm3_initialise_state()` at USB mount

4. **Add report framing** in the IN/OUT report path
   - Gate `[0x0B, 0x14, ...]` prefix on `TOY_PROFILE_XBOX360`
   - Strip the 2-byte header from OUT reports before passing to the command handler

5. **Add GPIO for switch (D0) and status LED (D1)**
   - `pinMode(D0, INPUT_PULLUP)` + `pinMode(D1, OUTPUT)` before USB init
   - Read at boot: `profile = (digitalRead(D0) == LOW) ? PROFILE_XBOX360 : PROFILE_PLAYSTATION`
   - `digitalWrite(D1, profile == PROFILE_PLAYSTATION ? HIGH : LOW)`
   - Poll D0 in `loop()` with 50 ms debounce; on stable change: detach USB, reset XSM3 state,
     reconfigure descriptors, reattach USB, update D1

6. **Optional: NeoPixel mode indicator**
   - Show green (Xbox) or blue (PS) continuously; flash briefly during switch transition

7. **Verify Xbox 360 LEGO Dimensions VID:PID**
   - Capture USB traffic from real Xbox 360 + LEGO Dimensions hardware
   - Update descriptor constants once confirmed

---

## 9. References

- [brandonw.net/360bridge/doc.php](https://www.brandonw.net/360bridge/doc.php) — Xbox 360 XSM3 protocol detail
- [github.com/InvoxiPlayGames/libxsm3](https://github.com/InvoxiPlayGames/libxsm3) — libxsm3 (canonical)
- [github.com/MrMEEE/libxsm3](https://github.com/MrMEEE/libxsm3) — RP2040 fork
- [github.com/sanjay900/portal_of_flipper](https://github.com/sanjay900/portal_of_flipper) — validated PS + Xbox 360 portal emulator on Flipper Zero (reference implementation)
- [github.com/tresni/PoweredPortals/wiki/USB-Protocols](https://github.com/tresni/PoweredPortals/wiki/USB-Protocols) — Skylanders command layer reference
- `docs/xbox360-auth-donor-strategy.md` — donor board auth fallback strategy
- `docs/platform-support.md` — PlatformIO environment design, profile model

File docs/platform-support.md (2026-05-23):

# Platform Support Strategy

## Current priority

- PlayStation Toy Pad compatibility first.
- Verify end-to-end flow on PlayStation profile before adding Xbox-specific behavior.

## Why staged support

- USB identity details may differ between PlayStation and Xbox 360 Toy Pads.
- Xbox 360 can require additional behavior that should be implemented after baseline is stable.

## Planned approach

1. Implement RP2040 USB descriptors and control/report behavior for PlayStation target.
2. Capture and compare traffic against real PlayStation Toy Pad.
3. Add profile switch in RP2040 firmware for Xbox 360 mode.
4. Capture and compare traffic against real Xbox 360 Toy Pad.
5. Add profile-specific descriptor/report/timing differences.
6. If Xbox auth behavior blocks pure emulation, use donor-board auth strategy in `docs/xbox360-auth-donor-strategy.md`.

## Firmware profile model

Use a runtime profile enum in RP2040 firmware:

- `PROFILE_PLAYSTATION`
- `PROFILE_XBOX360`

The profile should gate:

- USB descriptors
- report format details
- control request handling quirks
- timing/heartbeat behavior if needed

PlatformIO build environment:

- Single unified build: `console_rp2040` (profile selected at runtime via GPIO switch)

The compile-time `TOY_PROFILE_XBOX360` flag has been removed; both profiles are compiled
in and the active profile is determined by reading the mode switch GPIO at boot and
continuously at runtime.

## Xbox 360 strategy note

- For first Xbox milestone, prefer full donor-board auth reuse over chip-only transplant.
- Move to auth-island/chip transplant only after non-destructive captures and repeatable handshake behavior are confirmed.
- Detailed workflow: `docs/xbox360-auth-donor-strategy.md`
- Optional jailbroken-console path (JTAG/RGH) is tracked in `docs/xbox360-auth-donor-strategy.md` via consolemods guidance.

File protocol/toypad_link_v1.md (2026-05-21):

# Toy Pad Link Protocol v1

This protocol is used across two logical links:

- **Link A**: pad-esp32 ↔ console-esp32 over Wi-Fi TCP (not UDP — original spec was provisional)
- **Link B**: console-esp32 ↔ console-rp2040 over UART (115 200 baud)

Wi-Fi mode for Link A:

- Console ESP32 is a SoftAP (SSID `ToyPadConsole-{CHIPID}`, open, IP 192.168.44.1).
- Pad ESP32 joins console SoftAP as station after provisioning.
- TCP server on port 25100. `setNoDelay(true)` on both ends. `WiFi.setSleep(false)` on pad.

## Frame format

```
[0]  sync0   = 0x4C  ('L')
[1]  sync1   = 0x44  ('D')
[2]  version = 0x01
[3]  type    (see below)
[4]  seq     (per-sender, wraps at 256)
[5]  length  (payload byte count, 0..64)
[6..6+length-1]  payload
[6+length..6+length+1]  CRC16-CCITT (init=0xFFFF, poly=0x1021, big-endian)
```

Maximum wire size: 6 (header) + 64 (payload) + 2 (CRC) = 72 bytes.

## Message types

| Value | Name | Direction | Description |
|---|---|---|---|
| 0x01 | HELLO | both | Heartbeat / pairing identity |
| 0x10 | TAG_SET | pad→console, console→RP2040 | Figure placed on a slot |
| 0x11 | TAG_CLEAR | pad→console, console→RP2040 | Figure removed from a slot |
| 0x20 | LED_CMD | RP2040→console→pad | Zone LED colour command |
| 0x30 | PAIR_SET | console→pad | Deliver shared pairing secret |
| 0x40 | DEBUG | any | Diagnostic text string (not forwarded by console) |
| 0x7F | ACK | any | Acknowledge a received frame |

## Payload formats

### HELLO (0x01)

| Sender | Length | Payload |
|---|---|---|
| Pad (enrollment) | 1 | `[0xa1]` |
| Pad (authenticated) | 5 | `[0xa1, secret_u32_le[0..3]]` |
| Console→RP2040 heartbeat | 1 | `[0xb1]` |
| RP2040→Console heartbeat | 1 | `[0x02]` |

### TAG_SET (0x10)

```
[0]  slot   (1–7)
[1..4]  toyId_u32_le
```

`toyId` is the first 4 bytes of the NFC UID (little-endian) for physical figures,
or a virtual toy ID assigned by the user.

### TAG_CLEAR (0x11)

```
[0]  slot   (1–7)
```

### LED_CMD (0x20)

```
[0]  zone   (0=center, 1=left, 2=right, 0xFF=all zones)
[1]  r
[2]  g
[3]  b
```

### PAIR_SET (0x30)

```
[0..3]  secret_u32_le
```

### DEBUG (0x40)

```
[0..length-1]  UTF-8 text (not null-terminated)
```

Used by pad-esp32 to relay WiFi diagnostics to console (format: `"rssi=-47 wf=3"`).
The console prints it as `[pad-dbg] …` and does not forward it to the RP2040.

### ACK (0x7F)

```
[0]  seq of the frame being acknowledged
```

## Reliability strategy

Only the **pad-esp32** implements retry logic:

- Frames sent with `trackAck=true` are stored in a single-slot `pending` buffer.
- Retry interval: `kRetryMs=50ms`, max retries: `kMaxRetries=3`.
- If the ACK arrives (matching `pending.seq`), `pending.active=false`.
- If retries are exhausted the frame is dropped silently (link recovery relies on periodic state sync).

`trackAck=true` is used for: HELLO (both modes), physical TAG_SET/TAG_CLEAR.  
`trackAck=false` (fire-and-forget) is used for: state-sync TAG_SET re-broadcasts, ACK responses, DEBUG frames.

The **console-esp32** does not retry; it relies on the 1-second state sync to re-deliver
any lost TAG_SET or LED_CMD.

## Pairing model

1. Pad connects to console AP, opens TCP socket.
2. Pad sends `HELLO [0xa1]` (no secret) or `HELLO [0xa1, secret]` (known secret).
3. Console validates:
   - Length=1 → enrollment: generates `esp_random()` secret, saves, sends `PAIR_SET`.
   - Length=5 with matching secret → re-pair: sends `PAIR_SET` with same secret.
   - Mismatch → ignored.
4. Pad receives `PAIR_SET`, saves secret to NVS, sends ACK, enters paired state.
5. Subsequent connections skip enrollment and go straight to step 2 with the stored secret.

Console accepts any new TCP connection and replaces an existing stale one. The pad
always reconnects immediately after detecting disconnect (`client.stop()` + CONN_SEARCHING).

## Security

No crypto on the link itself. The 32-bit shared secret prevents a rogue device from
pairing without access to a prior session. Add HMAC or AES-GCM in v2 if the link
is exposed to untrusted networks.

## Notes

- The LP frame parser (`lp_stream_push`) is byte-streaming: it tolerates arbitrary
  TCP segmentation and UART framing gaps.
- `seq` wraps at 256. The retry window (3 × 50 ms) is short enough that wrap
  collision with a live pending frame is not a practical concern.
- Do not optimize packet size until end-to-end behavior is fully verified.
- Full system architecture, timing constants, zone/slot mappings, and USB HID protocol
  details are in `docs/communication-architecture.md`.

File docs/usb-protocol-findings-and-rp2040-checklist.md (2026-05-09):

# USB Protocol Findings and RP2040 Implementation Checklist

This document captures practical findings from:

- https://github.com/woodenphone/lego_dimensions_protocol
- https://wasabifan.github.io/ev3dev.github.io/docs/tutorials/using-lego-dimensions-toy-pad/

The goal is to turn those findings into concrete RP2040 firmware tasks.

## Confirmed protocol facts (PS profile baseline)

1. USB identity and endpoints
- VID:PID `0x0e6f:0x0241`
- HID interface
- Interrupt OUT endpoint `0x01`, 32-byte packets
- Interrupt IN endpoint `0x81`, 32-byte packets

2. Packet shape
- Byte 0: `0x55` magic
- Byte 1: payload length (logical command length)
- Byte 2: command byte (OUT packets)
- Byte 3: message counter (commonly incrementing)
- Final non-zero byte before padding: checksum
- Packet is padded to 32 bytes with zeroes

3. Checksum
- 1-byte overflow add over command bytes (sum modulo 256)

4. Known startup command
- Startup command bytes before padding:
  - `55 0f b0 01 28 63 29 20 4c 45 47 4f 20 32 30 31 34 f7`
- Then zero padding to 32 bytes

5. Known LED-related commands (OUT endpoint)
- `0xc0`: immediate color one/all pads
- `0xc2`: fade one/all pads
- `0xc3`: flash one/all pads
- `0xc6`: fade all three pads independently
- `0xc7`: flash all three pads independently
- `0xc8`: set all three pads independently

6. NFC event direction hints
- IN endpoint (`0x81`) carries tag-related traffic
- Tutorials and notes indicate tag event packets that can begin with `0x56`
- Fields typically include pad index, action (insert/remove), and UID bytes

7. Xbox caveat
- Both references focus on PS/Wii-type portal behavior
- Xbox variant is noted as different and not covered by those scripts

## Additional findings from Proxmark thread

Source:
- https://www.proxmark.io/www.proxmark.org/forum/viewtopic.php?id=2657&p=2

1. Internal hardware observations (matches current board investigation)
- Main MCU in the LPC11U2x/U3x family
- NFC frontend reported as MFRC630
- LED driving assisted by HEF4049B buffer logic
- Three antennas are present and switched by the MCU

2. HID message families are reinforced
- Host -> portal commands: `0x55, len, cmd, msg#, payload..., checksum, pad`
- Portal -> host replies: `0x55, len, msg#, payload..., checksum, pad`
- Tag events: `0x56, len, zone, ..., action, uid..., checksum, pad`

3. Tag-event example (captured)
- `56 0b 03 00 00 00 04 2a b5 d2 a2 40 80 7b ...`
- Interpreted in-thread as:
  - `03` zone right (center `01`, left `02`)
  - action byte `00` for placed (`01` removed)
  - 7-byte UID follows

4. `0xD2` / `0xD3` command clues
- `0xD2` appears tied to tag read requests
- `0xD3` appears tied to tag write requests
- Example request: `55 04 d2 08 00 26 59`
- Example response family discussed: `55 12 ...` with returned page-group data

5. Important session/authentication clue
- Replaying only `B0` + basic commands can still be insufficient for protected reads/writes
- Thread reports `B1` and `B3` vary per connection and likely participate in a challenge-response/session unlock path
- Practical implication: full tag read/write behavior likely requires reproducing dynamic handshake behavior, not static command replay only

6. Debug port observations
- Pads near `J2` are reported to map to reset/SWD-style signals rather than classic JTAG pins
- LPC11Uxx notes in-thread: JTAG is not the normal debug path, SWD is; access can be limited by code-read-protection settings

## What this changes in our implementation plan

1. Keep PS profile as primary baseline
- Existing HID parser and LED command plan remains correct

2. Split RP2040 scope into two phases
- Phase A: emulate LED + tag event behavior used during normal gameplay (no protected tag write path)
- Phase B: implement or proxy advanced `D2/D3` behavior only after handshake/session behavior is characterized

3. Add explicit backlog items
- Track `B1/B3` dynamic exchange and message sequencing
- Add capture-driven tests for `D2` read path with and without fresh session handshake
- Keep `D3` write support gated behind validated auth/session model

## Practical near-term test updates

Add these tests to bring-up:

1. Tag event conformance test (`0x56`)
- Verify zone/action/uid mapping exactly matches known captures

2. Session freshness test
- Reconnect emulated portal and verify dynamic fields for `B1/B3` are accepted by host

3. `D2` probe test (read path)
- Confirm whether host requests produce valid portal response without protected-page workflow

4. Strict non-goal for first milestone
- Do not block first playable prototype on `D3` write support

## Scope boundaries for this repo

- These findings are ideal for the console-facing USB emulation layer on RP2040.
- They do not fully solve internal Toy Pad PCB takeover between LPC11U24 and onboard NFC chips.

## RP2040 implementation checklist (do this order)

1. Build PS profile USB baseline
- Implement USB descriptors for PS profile
- Expose HID interface with EP OUT `0x01` and EP IN `0x81`
- Fix report size at 32 bytes

2. Add packet codec in RP2040 firmware
- Parse 32-byte OUT packet with validated `0x55` magic
- Extract length, command, counter, args, checksum
- Recompute checksum and reject invalid packets

3. Implement command dispatcher (first 5 commands)
- `0xb0` startup handling
- `0xc0` immediate single/all pad color
- `0xc8` per-pad immediate color set (center/left/right)
- `0xc2` single-pad fade/pulse
- `0xc3` single-pad flash

4. Add IN endpoint reply scaffolding
- Keep a periodic/status packet path for EP `0x81`
- Add a queue for synthetic NFC events coming from ESP32 bridge

5. Bridge integration points
- Map ESP32 `LP_MSG_TAG_SET` and `LP_MSG_TAG_CLEAR` into HID IN event packets
- Map USB LED commands to internal LED state structure and forward to ESP32 side

6. Conformance tests
- Verify startup sequence accepted by game
- Verify checksum handling with known test vectors
- Verify LED commands `c0` and `c8` round-trip through ESP32 pad side
- Verify tag insert/remove path through IN packets

## Suggested parser and state structures (C/C++)

Use small fixed-size structures to keep timing deterministic.

```c
typedef struct {
  uint8_t raw[32];
  uint8_t length;
  uint8_t command;
  uint8_t counter;
  const uint8_t* args;
  uint8_t args_len;
  uint8_t checksum;
  bool valid_magic;
  bool valid_checksum;
} ToyPadOutPacket;

typedef struct {
  bool enable;
  uint8_t r;
  uint8_t g;
  uint8_t b;
} PadRgb;

typedef struct {
  PadRgb center;
  PadRgb left;
  PadRgb right;
  uint8_t last_counter;
  bool initialized;
} ToyPadState;
```

Checksum helper:

```c
static uint8_t toy_checksum(const uint8_t* bytes, uint8_t len) {
  uint16_t sum = 0;
  for (uint8_t i = 0; i < len; ++i) {
    sum += bytes[i];
  }
  return (uint8_t)(sum & 0xff);
}
```

## Immediate next coding steps in this repo

1. In `firmware/console-rp2040/src/main.cpp`
- Add a 32-byte USB packet parser and checksum validator
- Add command switch for `0xb0`, `0xc0`, `0xc8`, `0xc2`, `0xc3`

2. Add RP2040 USB profile constants
- Add VID/PID, endpoint IDs, and report size constants
- Keep them behind `PROFILE_PLAYSTATION` for now

3. Add a minimal test harness path
- On valid `0xc0` and `0xc8`, print parsed values to serial for first validation
- Then wire these fields into bridge forwarding to console ESP32

## Traceability notes

These findings are reverse-engineering references used for interoperability and testing. Keep this file updated when new captures are validated, especially for:

- Xbox profile differences
- EP `0x81` NFC payload layout confirmation
- command corner cases and timing constraints

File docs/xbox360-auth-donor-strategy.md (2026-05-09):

# Xbox 360 Auth Donor Strategy

This document describes a practical path for Xbox 360 support where the likely blocker is console authentication hardware behavior.

## Summary

- Yes, a donor approach is viable.
- No, chip-only transplant is usually not the first choice.
- Best first path: keep a full Xbox Toy Pad donor board intact and use it as an auth coprocessor while emulating/bridging the rest.

## Why this matters

For PS/Wii-style devices, HID protocol emulation can be enough for core gameplay behavior. For Xbox 360, there is often additional authentication behavior at the USB/peripheral layer. If that behavior is tied to a dedicated auth element or tightly coupled board logic, pure software emulation can be significantly harder.

## Three integration options (recommended order)

1. Full donor board reuse (recommended)
- Keep Xbox donor Toy Pad board intact.
- Treat it as a black-box auth/peripheral block.
- Bridge your RP2040/ESP32 logic around it.
- Pros: lowest hardware risk, fastest path to first success.
- Cons: larger physical assembly.

2. Auth island transplant (conditional)
- Move the suspected auth IC plus immediate support network (clock, decoupling, reset pull parts, related EEPROM if present).
- Pros: smaller final hardware than full donor board.
- Cons: medium to high rework complexity; still risk of missing dependencies.

3. Chip-only transplant (last resort)
- Move only the auth chip onto your custom board.
- Pros: smallest footprint.
- Cons: highest failure risk; often blocked by hidden dependencies.

## Recommended architecture with your current project

Use a 4-block console-side design for Xbox mode:

1. RP2040
- USB-facing emulation/bridge controller.
- Profile switch: `PROFILE_PLAYSTATION` and `PROFILE_XBOX360`.

2. Console ESP32
- Existing Wi-Fi/UART bridge role remains unchanged.

3. Xbox donor auth block
- Full donor board preferred first.
- Connected non-destructively for traffic observation before any intrusive changes.

4. Pad ESP32
- Existing physical Toy Pad sensing and event forwarding remains unchanged.

## Non-destructive validation plan (do this before desoldering)

1. Baseline capture
- Record USB traffic for stock Xbox setup during boot, idle, tag place/remove, and LED changes.

2. Donor line mapping
- Identify donor board rails, reset, clocks, and data buses.
- Confirm logic levels are 3.3 V before attaching probes/MCUs.

3. Passive sniff
- Attach high-impedance logic analyzer only.
- Confirm reproducible traffic signatures.

4. Bridge rehearsal
- Keep donor board active and intact.
- Verify your RP2040/ESP32 can run in parallel without disturbing donor behavior.

5. Controlled intervention
- Only after stable captures: isolate one signal path at a time.
- Re-test after each change.

## Decision gate for transplant

Proceed to auth island or chip transplant only if all are true:

1. Required auth behavior is isolated to a clear, repeatable subcircuit.
2. Clock/reset dependencies are fully identified.
3. You can reproduce required handshake behavior in controlled tests.
4. You have at least one spare donor board for failure recovery.

## Risk and effort estimate

1. Full donor-board reuse
- Difficulty: medium
- Typical effort: 1 to 2 weeks to first working prototype

2. Auth island transplant
- Difficulty: medium-high
- Typical effort: 2 to 4 weeks

3. Chip-only transplant
- Difficulty: high
- Typical effort: 3 to 6+ weeks

## Practical recommendation

For first Xbox 360 success, prioritize:

1. Full donor board reuse.
2. Capture-driven protocol diffing against PS profile.
3. Profile-gated RP2040 behavior updates.

After first stable success, optimize hardware footprint by attempting auth-island reduction.

## Jailbroken Xbox 360 alternative path

For JTAG/RGH-modded (jailbroken) Xbox 360 consoles, there is an optional alternative workflow documented by the modding community:

- https://consolemods.org/wiki/Xbox_360:Using_Modern_Controllers

How this can help this project:

1. It can reduce strict dependence on stock controller/auth pathways in some setups.
2. It can be useful as a test harness while Xbox Toy Pad auth bring-up is still in progress.
3. It provides a practical fallback path for users who already run homebrew dashboards/plugins.

Important scope note:

1. This is an optional, console-modded path and not a replacement for stock-console-compatible Xbox Toy Pad support.
2. Keep `PROFILE_XBOX360` donor-auth work as the primary path for broad compatibility.

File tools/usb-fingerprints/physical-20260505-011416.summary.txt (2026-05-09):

Bus 001 Device 021: ID 0e6f:0241 Logic3 LEGO READER V2.10

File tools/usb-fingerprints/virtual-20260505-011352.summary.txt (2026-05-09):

Bus 001 Device 020: ID 0e6f:0241 Logic3 LEGO READER V2.10

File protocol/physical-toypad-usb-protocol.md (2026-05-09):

# Physical LEGO Dimensions Toy Pad — USB Protocol Reference

Captured and decoded from: `firmware/console-pi/host/traces/physical-20260505-221015.pcapng`
Tool: `sudo tcpdump -nn -tttt -x -r <pcap>`
Host: Linux / RPCS3 HID driver
Physical device: OEM LEGO Dimensions Toy Pad (PDP)

---

## USB Descriptor Values

All values verified byte-for-byte from the usbmon enumeration capture.

### Device Descriptor

```
bLength:            18 (0x12)
bDescriptorType:    DEVICE (0x01)
bcdUSB:             0x0200  (USB 2.0)
bDeviceClass:       0x00    (defined per-interface)
bDeviceSubClass:    0x00
bDeviceProtocol:    0x00
bMaxPacketSize0:    64 (0x40)
idVendor:           0x0E6F
idProduct:          0x0241
bcdDevice:          0x0100
iManufacturer:      1  →  "LEGO READER V2.10"
iProduct:           2  →  "PDP LIMITED. "
iSerialNumber:      3  →  "P.D.P.000000"
bNumConfigurations: 1
```

Raw bytes: `12 01 00 02 00 00 00 40 6F 0E 41 02 00 01 01 02 03 01`

> **Note:** The physical device reports manufacturer=`"PDP LIMITED. "` and
> product=`"LEGO READER V2.10"`. `setup_gadget.sh` already matches that ordering.

### String Descriptors (English 0x0409)

| Index | Raw (first 4 bytes) | Decoded (UTF-16LE) |
|---|---|---|
| 0 | `04 03 09 04` | Language: 0x0409 (English US) |
| 1 | `24 03 4C 00 45 00 …` | "LEGO READER V2.10" (17 chars, 36 bytes) |
| 2 | `1C 03 50 00 44 00 …` | "PDP LIMITED. " (13 chars, 28 bytes) |
| 3 | `1A 03 50 00 2E 00 …` | "P.D.P.000000" (12 chars, 26 bytes) |

### Configuration Descriptor

```
bLength:              9
bDescriptorType:      CONFIGURATION (0x02)
wTotalLength:         0x0029 = 41
bNumInterfaces:       1
bConfigurationValue:  1
iConfiguration:       0  (no string)
bmAttributes:         0x80  (bus-powered, no remote wakeup)
bMaxPower:            0xFA = 250  (250 × 2 mA = 500 mA)
```

Raw (9-byte short form): `09 02 29 00 01 01 00 80 FA`

### Interface Descriptor

```
bLength:            9
bDescriptorType:    INTERFACE (0x04)
bInterfaceNumber:   0
bAlternateSetting:  0
bNumEndpoints:      2
bInterfaceClass:    0x03  (HID)
bInterfaceSubClass: 0x00
bInterfaceProtocol: 0x00
iInterface:         0
```

### HID Descriptor

```
bLength:            9
bDescriptorType:    HID (0x21)
bcdHID:             0x0100  (HID 1.00)
bCountryCode:       0x00
bNumDescriptors:    1
bDescriptorType[0]: 0x22  (Report)
wDescriptorLength:  0x001D = 29 bytes
```

### Endpoint Descriptors

Two interrupt endpoints — the physical uses **both** IN and OUT interrupt endpoints,
not a control-transfer fallback.

| EP Address | Direction | Type | wMaxPacketSize | bInterval |
|---|---|---|---|---|
| 0x81 | IN | Interrupt | 32 (0x0020) | 1 (1 ms at full-speed) |
| 0x01 | OUT | Interrupt | 32 (0x0020) | 1 (1 ms at full-speed) |

Full config+interface+HID+endpoints raw (41 bytes):
```
09 02 29 00 01 01 00 80 FA   ← configuration
09 04 00 00 02 03 00 00 00   ← interface (2 eps, HID class)
09 21 00 01 00 01 22 1D 00   ← HID (bcdHID=0x0100, report desc 29 bytes)
07 05 81 03 20 00 01          ← EP 0x81 IN  interrupt 32B interval=1
07 05 01 03 20 00 01          ← EP 0x01 OUT interrupt 32B interval=1
```

### HID Report Descriptor (29 bytes)

```
06 00 FF   Usage Page (Vendor Defined, 0xFF00)
09 01       Usage (0x01)
A1 01       Collection (Application)
19 01         Usage Minimum (1)
29 20         Usage Maximum (32)
15 00         Logical Minimum (0)
26 FF 00      Logical Maximum (255)
75 08         Report Size (8 bits)
95 20         Report Count (32)
81 00         Input  (Data, Array, Absolute)  ← IN report (pad → host)
19 01         Usage Minimum (1)
29 20         Usage Maximum (32)
91 00         Output (Data, Array, Absolute)  ← OUT report (host → pad)
C0          End Collection
```

Raw: `06 00 FF 09 01 A1 01 19 01 29 20 15 00 26 FF 00 75 08 95 20 81 00 19 01 29 20 91 00 C0`

---

## USB Enumeration Sequence

Timing from capture (relative to plug-in at t=0):

```
t+0.000s   GET_DESCRIPTOR(DEVICE)        → 18 bytes device descriptor
t+0.028s   GET_DESCRIPTOR(CONFIG, 9)     → 9 bytes (short, just config header)
t+0.055s   GET_DESCRIPTOR(CONFIG, 41)    → 41 bytes (full config+IF+HID+EPs)
t+0.085s   GET_DESCRIPTOR(STRING, 0)     → language list
t+0.113s   GET_DESCRIPTOR(STRING, 1)     → manufacturer string
t+0.116s   GET_DESCRIPTOR(STRING, 2)     → product string
t+0.119s   GET_DESCRIPTOR(STRING, 3)     → serial number string
t+0.122s   GET_DESCRIPTOR(STRING, 3)     → serial number string (fetched twice)
t+0.152s   SET_CONFIGURATION(1)          → no data
t+0.154s   GET_DESCRIPTOR(STRING, 3)     → serial number string (again)
```

After ~1.5 s, the HID driver (RPCS3) claims the interface and sends a second round:

```
t+1.598s   GET_DESCRIPTOR(CONFIG, 41)    → full config again (driver re-reads)
t+1.615s   HID SET_IDLE(0, 0)            → no data
t+1.636s   [HID GET_DESCRIPTOR(REPORT)]  → 29 bytes report descriptor
t+1.636s   ← FIRST INTERRUPT OUT: B0 wake command (see below)
```

The interrupt OUT and the last control transfer overlap — the HID driver queues
the first interrupt URB while the control pipe is still busy.

---

## HID Application Protocol (Wire Format)

All reports are **32 bytes**, zero-padded at the end.
Magic byte **0x55** is used in **both** directions (host→pad and pad→host).

### Host → Pad (command)

```
Offset  Size  Field
0       1     Magic = 0x55
1       1     Length = 2 + len(args)   (counts cmd + counter + args bytes)
2       1     Command (see table below)
3       1     Counter (monotonically increasing per session, host-owned)
4..N    N-2   Args (command-specific)
N+1     1     Checksum = sum(bytes[0..N]) & 0xFF
N+2..31 -     Zero padding
```

Checksum covers: magic + length + command + counter + args (all bytes before the checksum byte).

### Pad → Host (response)

```
Offset  Size  Field
0       1     Magic = 0x55
1       1     Length = 1 + len(data)   (counts counter + data bytes)
2       1     Counter echo (copy of host counter from the triggering command)
3..M    M-1   Response data (command-specific, may be empty)
M+1     1     Checksum = sum(bytes[0..M]) & 0xFF
M+2..31 -     Zero padding
```

**The pad response does NOT echo the command byte.**

> **⚠ Implementation note:** `toy_daemon.py`'s `build_reply()` currently uses
> magic=0x56 and includes a command echo byte, producing a different wire format
> than the physical.  The correct magic is 0x55 and there is no command echo.
> This discrepancy may cause RPCS3 to misinterpret responses (e.g. reading the
> command byte as the counter value).

### Checksum Examples (verified against capture)

B0 host command (counter=1, args="(c) LEGO 2014"):
```
55 0F B0 01 28 63 29 20 4C 45 47 4F 20 32 30 31 34 [F7] 00 00 00 00 00 00 00 00 00 00 00 00 00 00
sum(55..34) = 0x3F7 → & 0xFF = 0xF7 ✓
```

C0 host command (counter=2, set-all-color):
```
55 06 C0 02 00 FF 6E 18 [A2] 00 ...
sum(55 06 C0 02 00 FF 6E 18) = 0x2A2 → & 0xFF = 0xA2 ✓
```

C0 pad ACK (counter echo=2, empty data):
```
55 01 02 [58] 00 ...
sum(55 01 02) = 0x58 ✓
```

B0 pad response (counter echo=1, 24-byte data):
```
55 19 01 00 2F 02 01 02 02 04 02 F5 00 19 8D 54 8E 2D 5B AE 4E 00 42 17 01 00 15 [1B] 00 ...
sum(55 19 01 00 2F ... 15) = 0x51B → & 0xFF = 0x1B ✓
```

---

## Known Commands

### 0xB0 — Wake / Init

Sent once immediately after the HID interface is claimed.

**Host → Pad:**
```
55 0F B0 [ctr] 28 63 29 20 4C 45 47 4F 20 32 30 31 34 [cs]
                ↑────────────────────────────────────↑
                  "(c) LEGO 2014"  (13 bytes)
```

**Pad → Host** (24-byte identity/capability blob):
```
55 19 [ctr] 00 2F 02 01 02 02 04 02 F5 00 19 8D 54 8E 2D 5B AE 4E 00 42 17 01 00 15 [cs]
```

The 24-byte payload is a fixed identity blob from the physical firmware.
`toy_daemon.py` defines this as `B0_REPLY_PAYLOAD` — verified correct from capture.

---

### 0xB1 — Seed / Challenge Round 1

Part of an Xbox 360 / RPCS3 authentication handshake.  Sent immediately after B0.

**Host → Pad** (8-byte challenge):
```
55 0A B1 [ctr] [8 bytes challenge] [cs]
```

Capture example (counter=3):
```
55 0A B1 03 93 56 D2 D8 AB DD 58 E8 [6E] 00 ...
```

**Pad → Host** (8-byte response):
```
55 09 [ctr] [8 bytes response] [cs]
```

Capture example (counter echo=3):
```
55 09 03 19 CB F5 54 0F E2 37 25 [DB] 00 ...
```

The 8-byte challenge/response values appear to be cryptographic material.
The physical pad computes these from an embedded key.  An emulator that does
not implement the handshake should still ACK (return an 8-byte zeroed or dummy
response); RPCS3 continues regardless.

---

### 0xB3 — Seed / Challenge Round 2

Structurally identical to 0xB1.  Sent after 0xB1.

Capture example (counter=4):
```
Host: 55 0A B3 04 C0 B7 4F CD 5E 28 D9 40 [48] 00 ...
Pad:  55 09 04 A0 CD F7 03 06 26 11 84 [8A] 00 ...
```

---

### 0xC0 — Set Color (single pad)

Sets the LED color for one pad zone.

**Host → Pad:**
```
55 06 C0 [ctr] [pad] [r] [g] [b] [cs]
```

`pad`: 0=all zones, 1=left, 2=center, 3=right.

Capture example (counter=2, all zones, r=0xFF, g=0x6E, b=0x18):
```
55 06 C0 02 00 FF 6E 18 [A2] 00 ...
```

**Pad → Host** (empty ACK):
```
55 01 [ctr] [cs]
```

---

### 0xC6 — Fade All Zones (animation)

Sets a timed fade animation for all three zones simultaneously.
Sent continuously by RPCS3 at approximately **1.2-second intervals** during
normal operation (the "startup rainbow" and idle animations).

**Host → Pad:**
```
55 14 C6 [ctr] [zone1_6B] [zone2_6B] [zone3_6B] [cs]
```

Each 6-byte zone block:
```
[effect] [duration] [count] [r] [g] [b]
  0x01     0x1E      0x01   …   …   …
```

| Field | Observed values | Interpretation |
|---|---|---|
| effect | 0x01 | Fade in/out effect type |
| duration | 0x1E = 30 | Duration (frames or deciseconds) |
| count | 0x01 | Repeat count |
| r,g,b | various | Target RGB color |

Capture example — all zones set to red (counter=5):
```
55 14 C6 05  01 1E 01 FF 00 00  01 1E 01 FF 00 00  01 1E 01 FF 00 00  [91] 00 ...
```

**Pad → Host** (empty ACK):
```
55 01 [ctr] [cs]
```

Observed RPCS3 color cycling sequence (startup rainbow, zone colors):

| Counter | Zone 1 (L) | Zone 2 (C) | Zone 3 (R) |
|---|---|---|---|
| 5 | ff 00 00 (red) | ff 00 00 | ff 00 00 |
| 6 | ff 6e 00 (orange) | ff 6e 00 | ff 6e 00 |
| 9 | 00 6e 00 (green)  | 00 6e 00 | 00 6e 00 |
| 10 | 00 6e 18 (teal) | 00 6e 18 | 00 6e 18 |
| 11 | 00 00 18 (blue) | 00 00 18 | 00 00 18 |
| 12 | ff 00 18 (purple) | ff 00 18 | ff 00 18 |
| 13 | ff 00 00 (red) | ff 00 00 | ff 00 00 |

RPCS3 cycles through this rainbow and repeats. Each step takes ~1.2 s.

> **Note:** `toy_daemon.py` does not have an explicit handler for 0xC6 and falls
> through to the "unknown command" path which returns a correctly-checksummed ACK
> — sufficient for RPCS3 to continue.

---

### 0xC2 — Fade Color (single pad)

Structure suspected similar to 0xC6 but for one zone.  Not observed in this
capture.  `toy_daemon.py` ACKs it with an empty reply.

### 0xC3 — Flash (single pad)

Not observed in this capture.  `toy_daemon.py` ACKs with an empty reply.

---

## Unsolicited Events: Tag Placed / Removed

The pad spontaneously sends IN reports when an NFC tag enters or leaves a zone.
No tag events appear in this capture (no toys were present).

Based on cross-referencing with other LD emulator projects and `toy_daemon.py`:

**Pad → Host** (unsolicited, no counter echo):
```
Offset  Content
0       0x56  (unsolicited-event magic — distinct from 0x55 command magic)
1       0x0B  (length = 11)
2       0x56  (event type byte = tag event)
3       pad_zone  (1=left, 2=center, 3=right)
4       action    (0x00=placed, 0x01=removed)
5..11   NFC UID (7 bytes)
12      Checksum = sum(bytes[0..11]) & 0xFF
13..31  Zero padding
```

> **Unverified:** The 0x56 event magic was not observed in this capture.
> It may also be 0x55.  Verification requires a capture with an NFC toy present.

---

## Interrupt Endpoint Timing

### Physical behavior (observed)

```
After enumeration (~1.5 s):
  Control transfers: SET_IDLE, GET_DESCRIPTOR(REPORT)  ← last control activity
  
  t+0.000s:  [OUT] B0 wake command
  t+0.001s:  [IN ] B0 identity response
  t+0.002s:  [OUT] B1 challenge
  t+0.008s:  [IN ] B1 response
  t+0.059s:  [OUT] B1 challenge (second seed)
  t+0.060s:  [IN ] B1 response
  t+0.127s:  [OUT] B3 challenge
  t+0.074s:  [IN ] B3 response   ← auth complete
  t+0.261s:  [OUT] C6 fade-all (first animation command)
  t+0.290s:  [IN ] C6 ACK

Ongoing after init:
  ~1.2 s intervals:  [OUT] C6 fade-all  →  [IN] ACK
```

The host keeps **2 IN URBs permanently queued** on EP1 IN.  After each COMPLETE
a new SUBMIT is immediately posted.  This means:
- The interrupt endpoint never goes idle.
- The host can receive unsolicited tag events at any time without polling delay.

### Virtual behavior (before keepalive fix)

Only 3 interrupt packets observed (the B0 OUT + stale IN completion + B0 IN
response), then activity dropped to zero.  Cause: `toy_daemon.py` was not
writing periodic IN reports, so all queued host IN URBs expired/timed out and
the host stopped resubmitting them.

### Fix applied

`toy_daemon.py` was patched with a keepalive: after receiving the first host
command, a re-send of the last IN report fires every 100 ms if no natural
response has been sent.  This keeps EP1 IN active.

---

## Known Protocol Deviations in toy_daemon.py

These were discovered by comparing the physical capture against the emulator output.

| Aspect | Physical (correct) | Previous toy_daemon.py behavior |
|---|---|---|
| Response magic | `0x55` | `0x56` |
| Response format | `[0x55][len][counter][data][cs]` | `[0x56][len][cmd][counter][data][cs]` |
| Command echo in response | None | Echoed command byte |
| Length field meaning | `1 + len(data)` | `2 + len(data)` (included extra cmd byte) |

> The string descriptors already matched the physical device.
> The response magic/format bug has now been fixed in the daemon copies.

---

## Raw Packet Log (key frames)

Condensed from `physical-20260505-221015.pcapng`, device 1:60:

```
22:10:22.641890  OUT  55 0F B0 01 28 63 29 20 4C 45 47 4F 20 32 30 31 34 F7 …  ← B0 wake
22:10:22.643912  IN   55 19 01 00 2F 02 01 02 02 04 02 F5 00 19 8D 54 8E 2D …  ← B0 resp
22:10:22.702543  OUT  55 06 C0 02 00 FF 6E 18 A2 …                              ← C0 color
22:10:22.703913  IN   55 01 02 58 …                                              ← C0 ACK
22:10:22.768976  OUT  55 0A B1 03 93 56 D2 D8 AB DD 58 E8 6E …                  ← B1 seed
22:10:22.776915  IN   55 09 03 19 CB F5 54 0F E2 37 25 DB …                     ← B1 resp
22:10:22.834630  OUT  55 0A B3 04 C0 B7 4F CD 5E 28 D9 40 48 …                  ← B3 seed
22:10:22.853919  IN   55 09 04 A0 CD F7 03 06 26 11 84 8A …                     ← B3 resp
22:10:22.901309  OUT  55 14 C6 05 01 1E 01 FF 00 00 01 1E 01 FF 00 00 01 1E …  ← C6 anim
22:10:22.930923  IN   55 01 05 5B …                                              ← C6 ACK
22:10:24.135406  OUT  55 14 C6 06 01 1E 01 FF 6E 00 … 01 1E 01 FF 6E 00 … DC … ← C6 anim
22:10:24.144984  IN   55 01 06 5C …
22:10:24.534957  OUT  55 0A B1 07 8A 44 3B 9B 9D 43 96 8E BF …                  ← B1 (again)
22:10:24.562973  IN   55 09 07 5F BB 67 C2 B5 C6 EC 10 1F …
22:10:24.601130  OUT  55 0A B3 08 79 1C 8F 38 16 2B 91 B8 …                     ← B3 (again)
22:10:24.640041  IN   55 09 08 79 38 3C 3E 3F 7A 06 70 C0 …
  … (C6 color animation repeats at ~1.2 s intervals, B1/B3 re-seed ~every 2 s)
```

RPCS3 re-issues B1 and B3 seed rounds approximately every 2 seconds — this is a
periodic re-authentication ping.  The physical pad answers each one; an emulator
must respond (even with dummy bytes) to avoid a timeout.

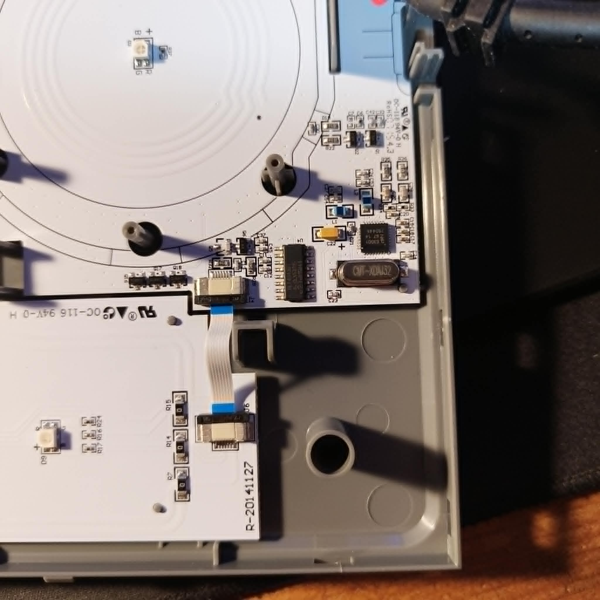
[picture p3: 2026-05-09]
pcb/pics/right.jpeg

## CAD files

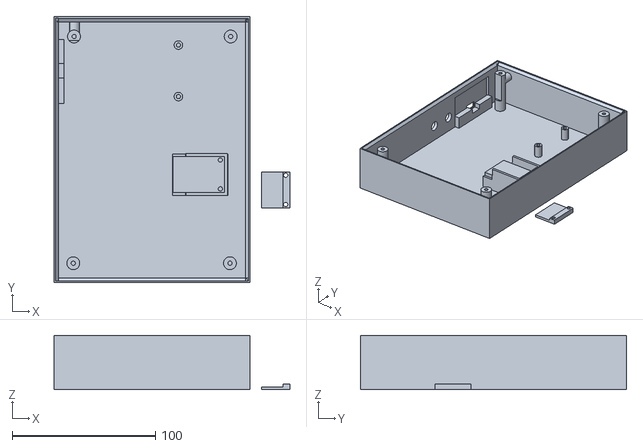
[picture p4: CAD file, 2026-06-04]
stl/Wireless Toypad v4.stl
165.0 x 186.0 x 38.0

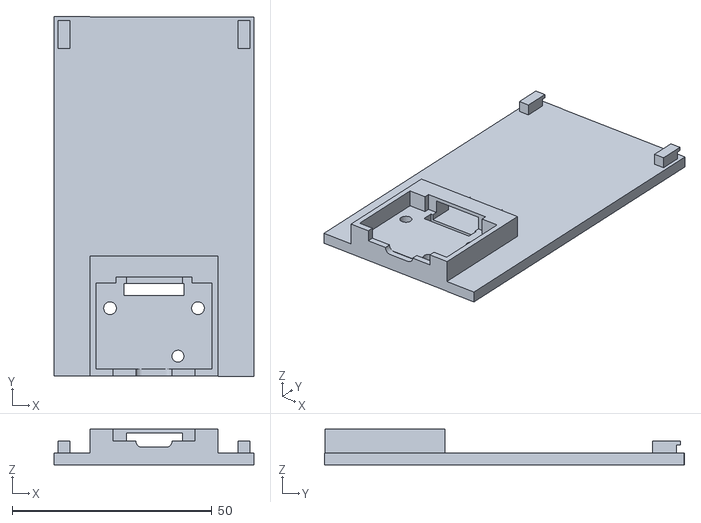
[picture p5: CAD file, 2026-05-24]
stl/Wireless Toypad Dongle v3 - Top.stl
50.0 x 90.1 x 9.00

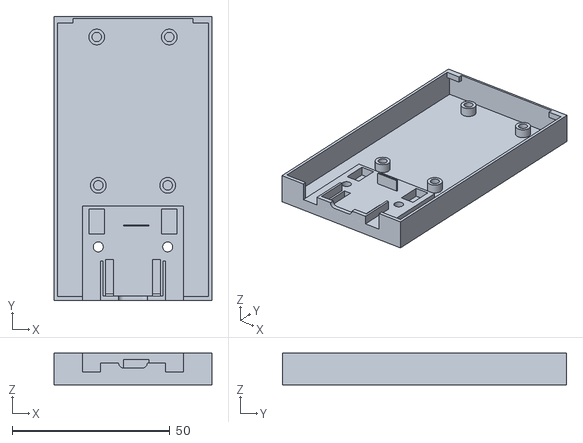
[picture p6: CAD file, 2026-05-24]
stl/Wireless Toypad Dongle v3 - Bottom.stl
50.0 x 90.0 x 10.0

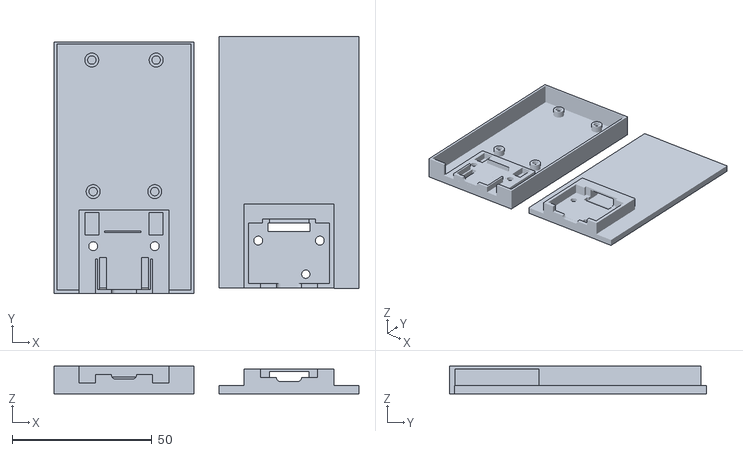
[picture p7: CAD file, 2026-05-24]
stl/Wireless Toypad Dongle v2.stl
109.0 x 92.0 x 10.0

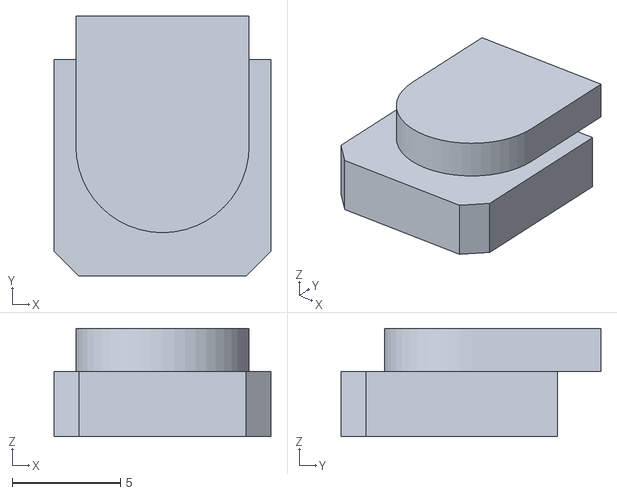
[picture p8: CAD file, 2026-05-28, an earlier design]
stl/Plate for Old outlet v1.stl
10.0 x 12.0 x 5.00

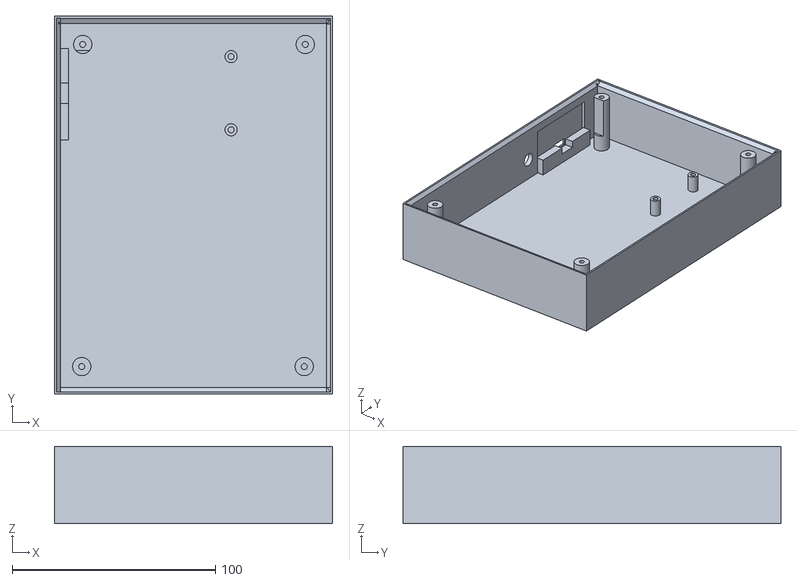
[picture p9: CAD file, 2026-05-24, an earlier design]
stl/Wireless Toypad v2.stl
137.0 x 186.0 x 38.0

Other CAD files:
stl/Wireless Toypad v3.stl
stl/Wireless Toypad Dongle v2 - Top.stl
stl/Wireless Toypad Dongle v1.stl
stl/Wireless Toypad Dongle v2 - Bottom.stl
stl/Wireless Toypad v1.stl

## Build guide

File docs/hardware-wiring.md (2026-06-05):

# Hardware Wiring Guide

## Overview

Three physical assemblies need to be wired:

| Assembly | Boards | Power source |
|---|---|---|
| **Console side** | XIAO RP2040 + Console ESP32 | USB port of PS4 / Xbox 360 |
| **Pad side** | Lolin ESP32-S2 Mini + physical Toy Pad | Any USB 5 V supply (charger / power bank) |

---

## 1. Console Side — XIAO RP2040 + Console ESP32

The RP2040 plugs into the console (PS4/Xbox) via its USB-C port. That USB port
also supplies 5 V for both boards.

```
PS4 / Xbox 360 USB port
        │
        │ USB-C cable
        ▼
┌─────────────────────┐
│   XIAO RP2040       │
│                     │
│  5V ─────────────────────► ESP32 VIN (5 V in)
│  GND ────────────────────► ESP32 GND
│  TX  (Serial1 / D6) ────► ESP32 RX (GPIO16)
│  RX  (Serial1 / D7) ◄─── ESP32 TX (GPIO17)
└─────────────────────┘
```

### Pin reference

| XIAO RP2040 | Signal | ESP32 |
|---|---|---|
| `5V` (USB pass-through) | Power | `VIN` |
| `GND` | Ground | `GND` |
| `D6` (TX / Serial1) | UART TX | `GPIO16` (U2RXD) |
| `D7` (RX / Serial1) | UART RX | `GPIO17` (U2TXD) |

### Additional pins — console-rp2040 (XIAO RP2040)

These pins are used for the profile switch and status indicators on the XIAO
RP2040 (PS3 vs Xbox 360 USB profile selection):

| XIAO RP2040 pin | GPIO | Signal | Notes |
|---|---|---|---|
| `D0` | 26 | Mode switch | `INPUT_PULLUP`; open/HIGH = PS3, pulled LOW = Xbox 360 |
| `D1` | 27 | PS3 status LED | HIGH = on when PS3 profile is active |
| `D2` | 28 | Xbox 360 status LED | HIGH = on when Xbox 360 profile is active |
| `11` | 11 | NeoPixel power enable | Drive HIGH to power the onboard NeoPixel |
| `12` | 12 | NeoPixel data | WS2812, 1 pixel; blue = PS3, green = Xbox 360 |

Connect a discrete LED (with series resistor, e.g. 330 Ω to GND) to each of
`D1` and `D2`. Only one LED is on at a time, immediately reflecting the active
USB profile. The NeoPixel mirrors the same state in colour.

> **Serial port:** The firmware uses `Serial1` on the RP2040 and `Serial2`
> (`HardwareSerial(2)`) on the ESP32 — both at 115 200 baud.

### Power budget — console USB port

| Component | Typical | Peak |
|---|---|---|
| XIAO RP2040 | 40 mA | 100 mA |
| ESP32 (Wi-Fi active) | 80 mA | 240 mA |
| **Total** | **120 mA** | **340 mA** |

PS4 front USB ports supply **500 mA** (USB 2.0); Xbox 360 side ports supply
**500 mA**.  The worst-case 340 mA fits comfortably within that budget.

---

## 2. Pad Side — ESP32-S2 Mini as USB Host

The ESP32-S2 Mini acts as a USB host to the physical Toy Pad.  
The Toy Pad stays **completely unmodified** — no soldering on the Toy Pad PCB.

### 2a. Recommended wiring: USB-A female → USB-C adapter (no soldering)

Use a **USB-A female to USB-C adapter** (or a short USB-A female ↔ USB-C
cable) to connect the toypad's intact USB cable to the S2 Mini's USB-C port.
Power the S2 Mini via its **VBUS + GND header pins** from an external 5 V
supply (power bank, charger, etc.).

```
Physical Toy Pad
  USB-A plug ──► USB-A female ↔ USB-C adapter ──► USB-C port on S2 Mini
                                                         (D− / D+ / VBUS)
External 5 V supply ─────────────────────────────► VBUS header pin on S2 Mini
                    ─────────────────────────────► GND  header pin on S2 Mini
```

> **Why VBUS header pin?**  GPIO 19 (D−) and GPIO 20 (D+) are the ESP32-S2's
> USB OTG lines and are **only** accessible via the USB-C connector — they are
> **not** broken out as solder pads on the header.  The USB-C port is therefore
> used for the toypad data connection.  5 V fed into the `VBUS` header pin
> powers the board and also flows through to the USB-C VBUS, supplying the
> toypad.

### 2b. Alternate wiring: cut cable + USB-C breakout board

If you prefer a permanent direct-wired connection, cut the toypad's USB-A
cable and connect the four wires to a **USB-C breakout board**, then plug
the breakout into the S2 Mini's USB-C port.  The S2 Mini still needs
external power via the VBUS + GND header pins.

```
Physical Toy Pad  USB cable
  Red   (VBUS 5V) ─────────────────► USB-C breakout VBUS
  Black (GND)     ─────────────────► USB-C breakout GND
  White (D−)      ─────────────────► USB-C breakout D−
  Green (D+)      ─────────────────► USB-C breakout D+
                             USB-C breakout ──► S2 Mini USB-C port

External 5 V supply ─────────────────────────► VBUS header pin on S2 Mini
                    ─────────────────────────► GND  header pin on S2 Mini
```

### 2c. Pin reference — S2 Mini ↔ Toy Pad USB

| Signal | ESP32-S2 Mini | Toy Pad USB cable |
|---|---|---|
| USB D− | USB-C connector D− (internal GPIO 19) | White wire |
| USB D+ | USB-C connector D+ (internal GPIO 20) | Green wire |
| 5 V (to toypad) | `VBUS` header pin → USB-C VBUS | Red wire |
| GND | `GND` header pin | Black wire |

> GPIO 19 / GPIO 20 are the ESP32-S2's native USB OTG lines.  On the S2 Mini
> they are wired directly to the USB-C connector and are **not** exposed as
> header pins — the USB-C port is the only way to access them.

### 2d. Power budget — pad side

| Component | Typical | Peak |
|---|---|---|
| ESP32-S2 Mini (WiFi active) | 80 mA | 240 mA |
| Physical Toy Pad (USB powered) | 80 mA | 160 mA |
| **Total** | **160 mA** | **400 mA** |

A USB power bank or any 5 V charger at 500 mA is sufficient.

---

## 2e. Status Indicator and Mode Button — Pad Side

A common-anode RGB LED and a push-button are added to the S2 Mini to show
connection/mode status and allow switching between physical-pad and emulator
mode without a computer.

### Wiring

```
ESP32-S2 Mini header                        Component
─────────────────────────────────────────────────────────────────────
GPIO 11  ───[330 Ω]──► RGB LED Red anode leg
GPIO 12  ───[330 Ω]──► RGB LED Green anode leg
GPIO 13  ───[330 Ω]──► RGB LED Blue anode leg
                        RGB LED Common Anode (+) ──► 3.3 V

GPIO 14  ───────────── Button one terminal
GND      ───────────── Button other terminal
```

> **Common-anode LED:** the shared anode (+) is tied to 3.3 V.
> Driving a pin **LOW** turns that colour **on**; **HIGH** turns it **off**.
> An internal `INPUT_PULLUP` is used for the button so no external resistor
> is needed — pressing the button pulls GPIO 14 to GND (active-low).

### Pin reference — pad-esp32 (ESP32-S2 Mini)

| GPIO | Signal | Direction | Notes |
|---|---|---|---|
| `11` | RGB Red | Output | LOW = on (common-anode) |
| `12` | RGB Green | Output | LOW = on |
| `13` | RGB Blue | Output | LOW = on |
| `14` | Mode button | Input (PULLUP) | LOW = pressed |

### LED colour states

| Colour | Meaning |
|---|---|
| **Yellow** (Red + Green) | Not connected to console |
| **Green** | Connected — physical passthrough mode (physical Toy Pad active) |
| **Magenta** (Red + Blue) | Connected — emulator mode (console-esp32 manages virtual toys) |

### Mode switching

Pressing the button sends a toggle request (`LP_MSG_SET_MODE`) to the
console-esp32 over the existing WiFi/LP link.  The console-esp32 is the
authority on the current mode: it updates its own `runtimeMode`, persists it
to flash, clears stale slot state on the RP2040 if needed, and replies with
the new mode.  The pad-esp32 then updates its LED to reflect the confirmed
mode.

The mode can also be changed at any time from the console-esp32 web UI
(`/api/mode`); the pad LED will update automatically.

---

## 3. Pad Side (Advanced) — Direct MCU bypass

> This section describes bypassing the Toy Pad's internal MCU and wiring
> directly to the NFC chip and LED driver.  This is **not required** with the
> S2 Mini USB host approach above; it is kept for reference.

### 3a. Understanding the Toy Pad PCB

The PS3/PS4 round Toy Pad contains (visible in the PCB photo):

| Part | Role |
|---|---|
| ARM Cortex-M0 MCU (e.g. LPC11U35 or STM32F0) | Original host controller, talks USB HID to console |
| NFC frontend IC (typically **TRF7970A** or **PN532**) | Reads NTAG215 / Mifare tags; connects to MCU via SPI or I2C |
| RGB LED driver (WS2812 chain or discrete driver) | Powers the 3-zone lighting |
| Crystal oscillator | Clock for MCU |
| Multi-wire harness (red/black/green/white wires in photo) | Power + data to satellite boards / LED rings |

> To identify the exact ICs, look for the largest 32-pin (or QFP) package (MCU)
> and the second largest IC near the antenna traces (NFC frontend).  The chip
> markings will confirm the exact model.  Common markings to look for:
> - **TRF7970A** — TI NFC frontend (SPI)
> - **PN532** — NXP NFC controller (I2C, SPI, or UART)
> - **LPC11U35** — NXP ARM M0 (the original host MCU)
> - **STM32F042** — ST ARM M0

### 3b. Bypass wiring strategy

The cleanest approach is to leave the TRF7970A / PN532 in place, disable or
remove the original ARM MCU, and connect the Pad ESP32 directly to the NFC
frontend and LED chain.

```
Physical Toy Pad PCB
                      ┌─────────────────────────┐
              NFC     │  TRF7970A or PN532       │
              antenna ◄──────────────────────────┤
            (coil)    │  SPI / I2C pins           │
                      └───────┬─────┬────┬───────┘
                              │     │    │
              ┌───────────────┘     │    └──────────────────┐
              │                     │                       │
          SPI_MISO               SPI_SCK / SDA            SPI_MOSI / SCL
              │                     │                       │
   ┌──────────▼─────────────────────▼───────────────────────▼──────────┐
   │                       Pad ESP32                                    │
   │                                                                    │
   │  GPIO19 (MISO)    GPIO18 (SCK)    GPIO23 (MOSI)   GPIO5 (CS)     │
   │     ──────── SPI to NFC chip ────────────────────────────         │
   │                                                                    │
   │  GPIO4  ─────────────────────────────────────────► LED data (WS2812) │
   │                                                                    │
   │  5V ◄──── External USB 5V supply                                  │
   │  GND ──── GND (common with Toy Pad PCB GND)                       │
   └────────────────────────────────────────────────────────────────────┘
```

### 3c. Pin reference — Pad ESP32 ↔ NFC chip

#### If NFC chip is **TRF7970A** (SPI mode)

| TRF7970A pin | Signal | ESP32 GPIO |
|---|---|---|
| `MISO` / `DATA_OUT` | SPI MISO | `GPIO19` |
| `MOSI` / `DATA_IN` | SPI MOSI | `GPIO23` |
| `CLK` | SPI clock | `GPIO18` |
| `SS` / `CS` | Chip select | `GPIO5` |
| `MOD` | Modulator (keep HIGH) | 3.3 V via 10 kΩ |
| `IRQ` / `ASK` | Tag present interrupt | `GPIO4` (optional) |
| `VCC` | 3.3 V supply | `3.3 V` |
| `GND` | Ground | `GND` |

Use the [TRF7970A Arduino library](https://github.com/electricimp/TRF7970a) or
Adafruit's NFC library adapted for SPI.

#### If NFC chip is **PN532** (I2C mode)

| PN532 pin | Signal | ESP32 GPIO |
|---|---|---|
| `SDA` | I2C data | `GPIO21` |
| `SCL` | I2C clock | `GPIO22` |
| `IRQ` | Interrupt out | `GPIO4` |
| `RSTO` | Reset (optional) | `GPIO2` |
| `VCC` | 3.3 V | `3.3 V` |
| `GND` | Ground | `GND` |

Use `Adafruit_PN532` library with I2C; set `I2C_ADDRESS = 0x24` (the PN532
default when HSU/SPI pads are left floating).

> **Determining the interface mode:** Most Toy Pad TRF7970A chips are wired in
> SPI.  If you find exactly 4 data traces going from the NFC IC toward the old
> MCU (MOSI, MISO, SCK, CS) it is SPI.  Two traces with pull-ups suggests I2C.

### 3d. LEDs — WS2812 or custom driver

The Toy Pad RGB zones are typically driven by a WS2812B-compatible chain or an
SPI-based LED driver.  

- If the harness has a **single data wire** per zone (or a daisy-chain), it is
  likely WS2812/NeoPixel → connect to `GPIO4` and use the `Adafruit NeoPixel`
  or `FastLED` library.  
- If there are 3 wires per LED cluster (R, G, B + common), it is a simple PWM
  setup — drive with 3× `ledcWrite` channels on ESP32.

---

## 4. Power Supply for the Pad Side

Once the physical Toy Pad is modified it no longer plugs into the specific
console — it just needs **5 V USB power**.  Options, best-first:

| Option | Notes |
|---|---|
| USB power bank (slim) | Best — wireless pad is then fully wireless |
| Phone charger / wall adapter | Good for desk setups |
| Toy Pad original USB cable → any USB hub | Re-uses existing cable |
| Second USB port on the same PS4/Xbox | Feasible (see budget below) |

### Using the second USB port on the console

If you want both assemblies powered from the console:

```
Console USB port A ─── XIAO RP2040 (data + power)─── Console ESP32
Console USB port B ─── Pad ESP32 + Toy Pad PCB power
```

PS4 has 2 front USB 2.0 ports, each rated 500 mA.

| Pad-side component | Current |
|---|---|
| ESP32 (Wi-Fi active) | ~240 mA peak |
| NFC frontend (TRF7970A / PN532) | ~55 mA |
| WS2812 LEDs × 12 @ 20 mA | ~240 mA max (all white) |
| **Total worst case** | **~535 mA** |

That slightly exceeds a single 500 mA port at full LED brightness.  
**Mitigate** by capping LED brightness to 50 % in firmware (`FastLED.setBrightness(128)`) which brings the LED contribution down to ~120 mA, giving a safe total of ~415 mA.

> The Xbox 360 also has two USB 2.0 host ports (500 mA each), so the same
> strategy applies.

---

## 5. Summary — full system wiring

```
      ┌──── Console USB port A (data+power) ────┐
      │                                          │
      ▼                                          ▼
 XIAO RP2040  ◄──UART──►  Console ESP32  )))  ((( Pad ESP32 ◄──► NFC / LEDs
 (USB device)                (Wi-Fi AP)  Wi-Fi     (Wi-Fi STA)
                                                       │
                                       Console USB port B  (power only)
                                       -OR- USB power bank
```

---

## 5. Steps to identify your exact NFC chip

1. Open the Toy Pad (4 screws on the bottom).
2. Under bright light / magnifier, find the IC closest to the NFC coil antenna
   traces on the PCB.
3. Read the top marking — photograph under macro mode if needed.
4. Match to TRF7970A, PN532, or post the marking here for identification.
5. Count the wires going between that IC and the main MCU to confirm SPI (4)
   or I2C (2 + 2 pull-ups).

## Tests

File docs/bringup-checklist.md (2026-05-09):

# Bring-up Checklist (Direct AP + Pairing)

## 1) Flash order

1. Flash console RP2040 firmware.
2. Flash console ESP32 firmware.
3. Flash pad ESP32 firmware.

## 2) Configure pairing defaults

No pair code or AP password setup is required.

Console ESP32 creates an open AP named `ToyPadConsole-xxxxxx`.

## 3) Console-side UART wiring

- ESP32 TX -> RP2040 RX
- ESP32 RX <- RP2040 TX
- GND shared

## 4) Provision pad over local setup portal

1. Power pad ESP32 with no saved config.
2. Join Wi-Fi network `ToyPad-Setup` (password `toypadsetup`).
3. Open `http://192.168.4.1`.
4. Select console SSID (`ToyPadConsole-xxxxxx`), leave password empty for open AP.
5. Save and reboot. On first link, secret enrollment happens automatically.

## 5) Reset procedure (pad)

- Hold BOOT (GPIO0 low) for about 3 seconds during boot.
- Saved config is cleared and setup portal starts again.

## 6) Expected serial logs

### RP2040

- boot line
- periodic `link hello`
- periodic `TAG_SET zone=... toyId=...`

### pad ESP32

- station connected line
- `sent virtual TAG_SET ...`
- `ack received`

### console ESP32

- AP SSID (open) printed
- `paired with <ip>:<port>`
- no repeated bad frame logs

## 7) Failure symptoms

- `ack timeout` on pad: console ESP32 not reachable or frame rejected.
- `unpaired client ignored` on console: malformed HELLO or failed secret verification.
- `dropped bad UDP frame`: datagram corruption or protocol mismatch.
- `dropped bad crc` on RP2040: UART wiring/noise or baud mismatch.

## 8) Next implementation step

Replace RP2040 TODO USB hook with TinyUSB Toy Pad descriptors and endpoint handling.

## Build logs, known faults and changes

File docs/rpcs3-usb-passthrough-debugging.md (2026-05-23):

# RPCS3 USB Passthrough Debugging

This document records what was learned debugging RPCS3 failing to recognise
the RP2040-emulated Toy Pad while the real Toy Pad works fine.

---

## Symptom

RPCS3 launches and the Dimensions game never finds the Toy Pad. The device
enumerates correctly (VID:PID 0x0E6F:0x0241, correct descriptors) and
appears in `lsusb`, but the game UI shows no pad connected. RPCS3 re-reads
the configuration descriptor every ~1.7 seconds, indicating it is retrying
after the device fails to respond to its init command.

The RP2040 serial log (via ESP32 bridge on Serial1) prints only:

```
[rp2040] boot profile=ps usb vid=0x0e6f pid=0x0241
[rp2040] usb mounted
[rp2040] b0 stats rx=0 q=0 tx=0   ← repeats every 3s
```

`rx=0` means `onHidSetReport` is never called — the B0 init command is
never received by firmware, even though the USB host confirms the OUT
transfer completed.

---

## USB trace evidence

A `usbmon` capture (`physical-YYYYMMDD.pcapng` vs `virtual-YYYYMMDD.pcapng`)
shows the difference clearly.

### Real Toy Pad (working)

```
→ OUT ep1  55 0f b0 01 ...   [B0 command, 32 bytes]
← IN  ep1  55 19 01 00 2f ... [B0 reply,  32 bytes, arrives ~40ms later]
→ OUT ep1  55 06 c0 01 ...   [C0 command]
← IN  ep1  55 07 c0 01 ...
... full B0→C0→B1→B3→C6 handshake completes
```

### RP2040 (broken, before fix)

```
→ OUT ep1  55 0f b0 01 ...   [B0 command, 32 bytes — USB-level ACK confirmed]
← IN  ep1  (pending, never completed)
                              [RPCS3 waits 1.7s, gives up, re-enumerates]
```

The OUT transfer is acknowledged at the USB level (the host sees it
complete with `len=32`), but TinyUSB's `onHidSetReport` callback never
fires. The RP2040 never queues a B0 reply, so the pending IN URB sits
unanswered forever.

---

## Root cause

`tusb_config_rp2040.h` (Adafruit TinyUSB Library) defines:

```c
// HID buffer size Should be sufficient to hold ID (if any) + Data
#define CFG_TUD_HID_EP_BUFSIZE 64
```

This is an **unconditional** `#define` — no `#ifndef` guard. It is included
by `tusb_config.h`, which is included by every TinyUSB C source file.

Because it has no guard, it overrides the `-DCFG_TUD_HID_EP_BUFSIZE=32`
build flag set in `platformio.ini`. The command-line define is processed
first (at the logical start of each translation unit), but the header
redefines the symbol unconditionally when it is included later, so the
final value is always 64.

With `CFG_TUD_HID_EP_BUFSIZE=64` in effect:

1. TinyUSB calls `usbd_edpt_xfer(rhport, ep_out, buf, 64)` to pre-arm the
   HID OUT endpoint, telling the RP2040 USB DMA to collect 64 bytes.
2. RPCS3 sends a 32-byte OUT interrupt packet. The USB hardware ACKs it
   (the host sees the transfer complete at the USB level).
3. The RP2040 DMA is still waiting for the remaining 32 bytes — it never
   signals `XFER_COMPLETE`.
4. TinyUSB never calls `hidd_xfer_cb`, so `tud_hid_set_report_cb` /
   `onHidSetReport` is never invoked.
5. The B0 reply is never queued. The pending IN URB is never answered.
   RPCS3 times out and retries.

---

## Fix

In `extra_script.py` (run as a PlatformIO pre-build step), patch the
Adafruit TinyUSB Library copy in `.pio/libdeps/` to add the missing
`#ifndef` guard:

```c
#ifndef CFG_TUD_HID_EP_BUFSIZE
#define CFG_TUD_HID_EP_BUFSIZE 64
#endif
```

With the guard in place, the `-DCFG_TUD_HID_EP_BUFSIZE=32` build flag in
`platformio.ini` takes effect. TinyUSB arms the OUT endpoint with 32 bytes,
RPCS3's 32-byte B0 command triggers `XFER_COMPLETE`, `onHidSetReport` fires,
and the B0 reply is sent. RPCS3 completes the full handshake.

The platform is also pinned to
`maxgerhardt/platform-raspberrypi#v1.4.0-gcc14-arduinopico460`
(arduino-pico 4.6.0) to prevent a future automatic upgrade from
reintroducing the mismatch with a different library version.

---

## udev rule (required on host)

RPCS3's libusb passthrough requires the device to be accessible without
root. Add to `/etc/udev/rules.d/50-toypad.rules`:

```
SUBSYSTEM=="usb", ATTR{idVendor}=="0e6f", ATTR{idProduct}=="0241", MODE="0666"
```

Then reload rules:

```bash
sudo udevadm control --reload-rules && sudo udevadm trigger
```

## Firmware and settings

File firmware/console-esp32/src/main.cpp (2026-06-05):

#include <Arduino.h>
#include <DNSServer.h>
#include <Preferences.h>
#include <ctype.h>
#include <WiFi.h>
#include <WiFiClient.h>
#include <WiFiServer.h>
#include <WebServer.h>
#include <LittleFS.h>
#include <Update.h>

#include <esp_netif.h>    // for esp_netif_dhcps_option (short DHCP lease time)
#include <lwip/sockets.h>  // for direct ::send() — bypasses WiFiClient::_connected stale-errno
#include "link_protocol.h"
#include "fw_header.h"
#include "ld_catalog_data.h"

static const uint16_t kPadListenPort = 25100;
static const uint32_t kRp2040Baud = 115200;
static const uint32_t kHelloMs = 3000;
static const uint32_t kStateSyncMs = 1000;  // full-state broadcast interval
// If no LP frame arrives from the pad within this window, declare it disconnected.
// The pad sends pad-dbg every 1 s and HELLO heartbeat every 5 s, so 8 s gives ample
// margin while still recovering well within any human-perceptible timeout.
static const uint32_t kPadRxTimeoutMs = 8000;
static const uint16_t kDnsPort = 53;
static const uint16_t kHttpPort = 80;
static const uint8_t kSlotCount = 7;
static const uint8_t kLightZoneCount = 3;
static const uint8_t kToyboxLimit = 24;
static const uint32_t kDebugHeartbeatMs = 5000;
static const uint8_t kUsbCmdMaxLen = 96;
// Enable USB debug console to forward RP2040 debug messages (LP_MSG_DEBUG) to
// the ESP32 USB serial port so they can be read without a separate UART adapter.
static const bool kEnableUsbDebugConsole = true;

enum RuntimeMode : uint8_t {
  MODE_EMULATOR = 0,
  MODE_PASSTHROUGH = 1,
};

typedef struct {
  uint8_t r;
  uint8_t g;
  uint8_t b;
} LedZoneState;

typedef struct {
  bool occupied;
  uint32_t toyId;
  char label[24];
  uint8_t toyType;
  uint8_t zone;           // LP zone: 0=center, 1=left, 2=right
  bool isPhysical;        // true = came from pad-esp32 (physical NFC tag)
  bool fromToybox;
  uint8_t toyboxOriginIndex;
} SlotState;

typedef struct {
  bool inUse;
  uint32_t toyId;
  char label[24];
  uint8_t toyType;
} ToyboxEntry;

enum ToyType : uint8_t {
  TOY_UNKNOWN = 0,
  TOY_CHARACTER = 1,
  TOY_VEHICLE = 2,
};

WiFiServer tcpServer(kPadListenPort);
WiFiClient padClient;
lp_stream_parser_t tcpParser;
DNSServer dns;
WebServer web(kHttpPort);
Preferences prefs;
uint8_t seqCounter = 0;
lp_stream_parser_t uartParser;
IPAddress padIp;
bool     padKnown    = false;
bool     padPaired   = false;
uint32_t padLastRxMs = 0;  // millis() of last successfully-parsed LP frame from pad
uint32_t lastHelloMs = 0;
uint32_t lastStateSyncMs = 0;
uint32_t lastDebugHeartbeatMs = 0;
static char sPadD2Debug[LP_MAX_PAYLOAD + 1] = "";  // last NFC-variant diagnostic from pad

// NFC tag programmer state — set by /api/tag/program/begin, cleared on success/cancel.
static bool     sProgramModeActive    = false;
static uint32_t sProgramTargetId      = 0;
static uint8_t  sProgramTargetType    = TOY_UNKNOWN;
static char     sProgramTargetLabel[24] = {};
static uint8_t  sProgramStatus        = 0;   // 0=idle,1=waiting,2=success,3=fail
static bool     sProgramIntercepted   = false;
static uint8_t  sProgramInterceptedSlot = 0;
String apSsid;
uint32_t sharedSecret = 0;
RuntimeMode runtimeMode = MODE_EMULATOR;
bool ledStateKnown = false;  // true once RP2040 has sent at least one LED_CMD
uint32_t sLastLedCmdFromRp2040Ms = 0;  // millis() of last LED_CMD from RP2040; 0=never
LedZoneState lightZones[kLightZoneCount] = {};
SlotState padSlots[kSlotCount] = {};
ToyboxEntry toybox[kToyboxLimit] = {};
bool piConsoleBridgeMode = false;
char usbCmdBuf[kUsbCmdMaxLen] = {};
uint8_t usbCmdLen = 0;

// 3-state ANSI/VT escape filter for Pi console bridge output.
enum AnsiFilterState : uint8_t {
  ANSI_NORMAL    = 0,  // pass printable text through
  ANSI_AFTER_ESC = 1,  // saw 0x1b, waiting for type byte
  ANSI_IN_CSI    = 2,  // inside ESC [ ... sequence
  ANSI_IN_OSC    = 3,  // inside ESC ] ... sequence (terminated by BEL or ESC \)
};
AnsiFilterState piAnsiState = ANSI_NORMAL;

// ─── OTA / DFU ──────────────────────────────────────────────────────────────
static const char*    kOtaRp2040Path   = "/ota-rp2040.bin";
static const uint16_t kDfuChunkSize    = 1024;
static const uint8_t  kDfuAckByte      = 0x06;
static const uint8_t  kDfuNakByte      = 0x15;
static const uint32_t kDfuChunkToutMs  = 5000;
static const uint8_t  kDfuMaxRetries   = 3;

static File sOtaFile;
static bool sOtaError = false;
static bool sOtaConsoleValidated = false;
// Streaming-DFU state: the pad firmware is sent directly to the pad over TCP
// during the HTTP upload, eliminating LittleFS staging and the blocking write.
static uint8_t  sDfuStreamBuf[kDfuChunkSize];  // 1 KB DFU chunk accumulator
static uint16_t sDfuStreamPos    = 0;           // bytes filled in sDfuStreamBuf
static uint32_t sDfuStreamOff    = 0;           // byte offset of next DFU chunk
static bool     sDfuStreamActive = false;       // true after OTA_BEGIN is ACK'd
static char sRp2040Version[LP_MAX_PAYLOAD + 1] = "?";
static char sPadVersion[LP_MAX_PAYLOAD + 1]    = "?";
// Non-const so the linker places this string in the .data segment,
// making it scannable in the binary image for OTA target validation.
static const char kFwIdent[] __attribute__((used)) = FW_IDENT_STR;

static const char* kModePrefKey = "mode";

static uint32_t readU32Le(const uint8_t* p);
static void writeU32Le(uint8_t* p, uint32_t v);
static bool sendFrameUart(uint8_t type, const uint8_t* payload, uint8_t payloadLen,
                          uint8_t forceSeq = 0xff);
static bool sendFrameTcp(uint8_t type, const uint8_t* payload, uint8_t payloadLen,
                         uint8_t forceSeq = 0xff);
static bool waitTcpAckLocal(uint32_t timeoutMs);

static const char* toyTypeToString(uint8_t toyType);
static uint8_t toyTypeFromString(const String& s);
static uint8_t slotToLpZone(uint8_t slotNum);
static void sendManifestJson();
static void sendServiceWorkerJs();
static void sendAppIconSvg();
static void processUsbConsole();
static void processPiConsoleBridge();

static const char kPortalPage[] = R"HTML(
<!doctype html>
<html>
<head>
  <meta charset="utf-8">
  <meta name="viewport" content="width=device-width, initial-scale=1">
  <meta name="theme-color" content="#101827">
  <meta name="mobile-web-app-capable" content="yes">
  <meta name="apple-mobile-web-app-capable" content="yes">
  <meta name="apple-mobile-web-app-status-bar-style" content="black-translucent">
  <meta name="apple-mobile-web-app-title" content="Toy Pad Console">
  <link rel="manifest" href="/manifest.webmanifest">
  <link rel="icon" href="/icon.svg" type="image/svg+xml">
  <link rel="apple-touch-icon" href="/icon.svg">
  <title>Toy Pad Console</title>
  <style>
    :root { --bg:#111827; --panel:#1f2937; --muted:#93a0ba; --ink:#e5e7eb; --accent:#4f46e5; }
    * { box-sizing: border-box; }
    body { margin:0; background:linear-gradient(170deg,#101827,#1b2a40); color:var(--ink); font-family:"Trebuchet MS","Segoe UI",sans-serif; }
    .app { max-width:1160px; margin:0 auto; padding:14px; display:grid; gap:10px; }
    .card { background:rgba(25,34,52,.88); border:1px solid rgba(255,255,255,.14); border-radius:12px; padding:12px; }
    .top { display:flex; justify-content:space-between; align-items:center; gap:8px; flex-wrap:wrap; }
    .mode-pill { display:inline-flex; background:#202a3d; padding:4px; border-radius:999px; gap:6px; }
    .mode-pill button { border:0; background:transparent; color:var(--ink); border-radius:999px; padding:6px 10px; font-weight:700; }
    .mode-pill button.active { background:#f4b740; color:#222; }
    .install-btn { border:1px solid rgba(255,255,255,.25); background:#2f855a; color:#fff; border-radius:999px; padding:6px 12px; font-weight:700; display:none; }
    .install-btn.visible { display:inline-block; }
    .layout { display:grid; grid-template-columns:1fr; gap:10px; }
    .stack { display:grid; gap:10px; }
    .toggle-row { display:flex; gap:8px; flex-wrap:wrap; }
    .toggle-row button { border:1px solid rgba(255,255,255,.2); background:#23314c; color:var(--ink); border-radius:8px; padding:7px 10px; font-weight:700; }
    .toggle-row button.active { background:#3e6acc; border-color:#76a4ff; }
    .filter-row { display:grid; grid-template-columns:1fr 1fr; gap:8px; margin-top:8px; }
    .catalog-search { width:100%; margin-top:8px; background:#192438; color:var(--ink); border:1px solid rgba(255,255,255,.22); border-radius:8px; padding:8px; }
    .catalog-list { max-height:260px; overflow-y:auto; display:grid; gap:6px; margin-top:8px; }
    .catalog-item { display:grid; grid-template-columns:1fr auto; gap:8px; align-items:center; background:#162032; border:1px solid rgba(255,255,255,.12); border-radius:8px; padding:8px; font-size:.84rem; }
    .catalog-item small { color:var(--muted); display:block; }
    .catalog-item .actions { display:flex; gap:4px; }
    .catalog-item button { border:0; border-radius:7px; background:#4f7ce7; color:#fff; font-weight:700; padding:6px 8px; font-size:.78rem; }
    .catalog-item button:hover { background:#5a8ff5; }
    .token { border:0; border-radius:10px; min-height:66px; font-size:.76rem; font-weight:700; padding:12px 10px 10px; margin:2px; cursor:grab; }
    .token.character { background:linear-gradient(160deg,#7ed5ff,#4a85c0); color:#0c2538; }
    .token.vehicle { background:linear-gradient(160deg,#ffca75,#e2852c); color:#2d1808; }
    .token.selected { outline:3px solid #fff; }
    .token { position:relative; }
    .token-remove { position:absolute; top:2px; right:2px; width:16px; height:16px; border-radius:999px; border:0; background:rgba(123,29,24,.85); color:#fff; font-size:10px; line-height:16px; padding:0; font-weight:700; cursor:pointer; }
    .token-remove:hover { background:rgba(220,38,38,.95); }
    .touch-note { color:var(--muted); font-size:.82rem; margin-bottom:6px; }
    .status-row { display:flex; gap:8px; flex-wrap:wrap; }
    .badge { background:#273552; border:1px solid rgba(255,255,255,.2); border-radius:999px; padding:5px 8px; font-size:.84rem; }
    .pad-grid { display:grid; grid-template-columns:2fr 1fr 2fr; gap:12px; align-items:start; }
    .zone-col { display:flex; flex-direction:column; gap:8px; align-items:center; width:100%; }
    .zone-label { font-size:.72rem; font-weight:700; color:var(--muted); text-transform:uppercase; letter-spacing:.07em; padding:2px 0; }
    .slot { width:100%; max-width:130px; min-height:76px; border-radius:11px; background:#3b465e; border:1px solid rgba(255,255,255,.25); text-align:center; font-size:.76rem; line-height:1.15; padding:8px; display:flex; align-items:center; justify-content:center; position:relative; color:var(--muted); }
    .slot.filled { color:#ffffff; text-shadow:0 1px 2px rgba(0,0,0,.7); font-weight:700; }
    .slot.spacer { visibility:hidden; }
    .clear-slot { position:absolute; top:4px; right:4px; width:18px; height:18px; border-radius:999px; border:0; background:rgba(123,29,24,.85); color:#fff; font-size:11px; line-height:18px; padding:0; font-weight:700; }
    .modal-overlay { display:none; position:fixed; top:0; left:0; right:0; bottom:0; background:rgba(0,0,0,.7); z-index:1000; }
    .modal-overlay.active { display:flex; }
    .modal-content { background:var(--panel); border:1px solid rgba(255,255,255,.2); border-radius:16px; padding:24px; box-shadow:0 8px 32px rgba(0,0,0,.3); margin:auto; min-width:320px; }
    .modal-title { font-size:1.2rem; font-weight:700; margin-bottom:16px; color:var(--ink); }
    .slot-buttons { display:grid; grid-template-columns:repeat(auto-fit,minmax(60px,1fr)); gap:12px; }
    .slot-button { background:#3e6acc; border:2px solid rgba(255,255,255,.2); border-radius:10px; color:var(--ink); font-weight:700; padding:12px; font-size:1rem; cursor:pointer; }
    .slot-button:hover { background:#4f7ce7; border-color:#76a4ff; }
    .install-note { color:var(--muted); font-size:.82rem; margin-top:8px; }
    .prog-status { margin-top:12px; padding:10px; border-radius:8px; font-weight:700; text-align:center; display:none; }
    .prog-status.waiting { background:#1e3a5f; color:#93c5fd; display:block; }
    .prog-status.success { background:#14532d; color:#86efac; display:block; }
    .prog-status.fail    { background:#7f1d1d; color:#fca5a5; display:block; }
    @media (max-width:880px) { .layout { grid-template-columns:1fr; } }
  </style>
</head>
<body>
  <div class="app">
    <div class="card top">
      <div><b>Toy Pad Console Interface</b><div id="subtitle" style="color:var(--muted)">Loading...</div></div>
      <div style="display:flex; gap:8px; align-items:center; flex-wrap:wrap;">
        <button id="installBtn" class="install-btn">Install App</button>
        <div class="mode-pill" id="modePill"><button data-mode="emulator">Emulator</button><button data-mode="passthrough">Passthrough</button></div>
      </div>
    </div>
    <div class="card" id="installInfo" style="display:none;"><div class="install-note" id="installNote"></div></div>
    <div class="card"><div class="status-row" id="statusRow"></div><div id="d2dbg" style="font-size:.78rem;color:#94a3b8;margin-top:.4rem;font-family:monospace"></div></div>
    <div class="card"><h3 style="margin-top:0">The Toy Pad (7 slots)</h3><div class="pad-grid" id="padGrid"></div></div>
    <div class="layout">
      <div class="stack">
        <div class="card">
          <h3 style="margin-top:0">Toy Box</h3>
          <div class="touch-note" id="touchSelectionState">No toy selected.</div>
          <div class="toybox" id="toybox"></div>
        </div>
        <div class="card">
          <h3 style="margin-top:0">Catalog</h3>
          <div class="toggle-row"><button id="toggleCharacters" class="active">Characters</button><button id="toggleVehicles" class="active">Vehicles</button></div>
          <input id="catalogSearch" class="catalog-search" placeholder="Search by name or ID">
          <div class="filter-row">
            <input id="worldFilter" class="catalog-search" style="margin-top:0" placeholder="Filter by world">
            <input id="abilityFilter" class="catalog-search" style="margin-top:0" placeholder="Filter by ability">
          </div>
          <div class="catalog-list" id="catalogList"></div>
        </div>
      </div>
    </div>
  </div>

  <div class="modal-overlay" id="slotModal">
    <div class="modal-content">
      <div class="modal-title">Select a Slot</div>
      <div class="slot-buttons" id="slotButtons"></div>
    </div>
  </div>

  <div class="modal-overlay" id="progModal">
    <div class="modal-content">
      <div class="modal-title">&#9889; Flash NFC Tag</div>
      <p style="margin:0 0 4px">Vehicle: <b id="progVehicleName"></b></p>
      <p style="color:var(--muted);font-size:.86rem;margin:0 0 12px">Place a blank NTAG213 tag anywhere on the physical pad, then tap Flash.</p>
      <div id="progStatus" class="prog-status"></div>
      <div style="display:flex;gap:8px;margin-top:14px;">
        <button id="progFlashBtn" class="slot-button" style="flex:1;">Flash</button>
        <button id="progCancelBtn" class="slot-button" style="flex:1;background:#374151;border-color:#4b5563;">Cancel</button>
      </div>
    </div>
  </div>

  <script>
    // padRows removed — pad grid now renders by actual LP zone from /api/state
    const FAST_POLL_MS = 250;
    const SLOW_POLL_MS = 1200;
    let selectedToyboxIndex = null;
    let catalog = [];
    let filterCharacters = true;
    let filterVehicles = true;
    let catalogSearch = "";
    let catalogWorld = "";
    let catalogAbility = "";
    let deferredInstallPrompt = null;
    let refreshTimer = null;
    let refreshInFlight = false;
    let progPollTimer = null;

    function slotLabel(slot) {
      if (!slot.occupied) return "Empty";
      return `${slot.label || "Toy"}<br>0x${Number(slot.toyId).toString(16).toUpperCase()}`;
    }
    function slotZone(slotNum) {
      // LP zone 0=center, 1=left, 2=right
      // S2 = center; S1,S4,S5 = left; S3,S6,S7 = right
      if (slotNum === 2) return 0;
      if (slotNum === 1 || slotNum === 4 || slotNum === 5) return 1;
      return 2;
    }
    function rgbCss(o, a) {
      return `rgba(${Number(o.r)||0},${Number(o.g)||0},${Number(o.b)||0},${a})`;
    }
    // Game sends LED-calibrated PWM values for physical hardware.
    // Blue LEDs are ~11.6x more efficient per unit than red, green ~2.43x.
    // Scale channels so the physical white point (244,105,22) maps to (255,255,255).
    function ledCorrect(o) {
      return {
        r: Math.min(255, Math.round((o.r||0) * 1.05)),
        g: Math.min(255, Math.round((o.g||0) * 2.43)),
        b: Math.min(255, Math.round((o.b||0) * 11.6))
      };
    }
    function colorHex(c) { return (Number(c)&0xFF).toString(16).padStart(2,"0"); }
    function rgbHex(o) { return `#${colorHex(o.r)}${colorHex(o.g)}${colorHex(o.b)}`; }
    async function postJson(url, payload) {
      const r = await fetch(url, { method:"POST", headers:{"Content-Type":"application/json"}, body:JSON.stringify(payload||{}) });
      if (!r.ok) throw new Error(await r.text());
      return r.text();
    }
    function isIos() {
      return /iphone|ipad|ipod/i.test(navigator.userAgent);
    }
    function isInStandalone() {
      return window.matchMedia("(display-mode: standalone)").matches || window.navigator.standalone === true;
    }
    function showInstallNote(text) {
      const host = document.getElementById("installInfo");
      const note = document.getElementById("installNote");
      note.textContent = text;
      host.style.display = "block";
    }
    function setupInstallUx() {
      const installBtn = document.getElementById("installBtn");

      // Service worker requires HTTPS or localhost. SoftAP IP is typically HTTP only.
      if ((location.protocol === "https:" || location.hostname === "localhost") && "serviceWorker" in navigator) {
        navigator.serviceWorker.register("/sw.js").catch(() => {});
      }

      window.addEventListener("beforeinstallprompt", (e) => {
        e.preventDefault();
        deferredInstallPrompt = e;
        installBtn.classList.add("visible");
      });

      installBtn.onclick = async () => {
        if (deferredInstallPrompt) {
          deferredInstallPrompt.prompt();
          await deferredInstallPrompt.userChoice;
          deferredInstallPrompt = null;
          installBtn.classList.remove("visible");
          return;
        }
        if (isIos()) {
          showInstallNote("On iPhone/iPad: Share -> Add to Home Screen.");
          return;
        }
        showInstallNote("On Android: browser menu -> Add to Home screen. Full install prompt may require HTTPS.");
      };
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
void loop() {
  const uint32_t now = millis();

  if (kEnableUsbDebugConsole) {
    if (piConsoleBridgeMode) {
      processPiConsoleBridge();
      dns.processNextRequest();
      web.handleClient();
      delay(2);
      return;
    }

    processUsbConsole();
  }

  processTcpIn();
  processUartIn();
  dns.processNextRequest();
  web.handleClient();

  if ((now - lastHelloMs) >= kHelloMs) {
    lastHelloMs = now;
    sendHeartbeatToRp2040();
  }

  // Periodically re-broadcast full state on both links so peers recover after
  // a restart without waiting for the next change event.
  if ((now - lastStateSyncMs) >= kStateSyncMs) {
    lastStateSyncMs = now;
    // Active slots → RP2040 via UART. Only occupied slots need syncing;
    // empty slots are the RP2040's default state so TAG_CLEAR floods are
    // unnecessary and overflow its event queue.
    for (uint8_t s = 1; s <= kSlotCount; s++) {
      if (padSlots[s - 1].occupied) {
        sendTagSet(s, padSlots[s - 1].toyId, padSlots[s - 1].toyType);
      }
    }
    // All 3 LED zone states → pad-esp32 so it keeps the toypad lit.
    // Only send while the game is active (RP2040 LED_CMD seen within last 30 s).
    // When the game goes quiet the pad auto-reverts to standby green via its
    // own 30 s timeout without us pushing stale game colours at it.
    const bool gameNowActive = (sLastLedCmdFromRp2040Ms != 0) &&
                               (now - sLastLedCmdFromRp2040Ms) < 30000u;
    if (padKnown && padPaired && ledStateKnown && gameNowActive && runtimeMode != MODE_EMULATOR) {
      for (uint8_t z = 0; z < kLightZoneCount; z++) {
        const uint8_t ledPayload[4] = {z, lightZones[z].r, lightZones[z].g, lightZones[z].b};
        sendFrameTcp(LP_MSG_LED_CMD, ledPayload, sizeof(ledPayload));
      }
    }
  }

  if (kEnableUsbDebugConsole && (now - lastDebugHeartbeatMs) >= kDebugHeartbeatMs) {
    lastDebugHeartbeatMs = now;
    Serial.print("[console-esp32] alive mode=");
    Serial.print(runtimeMode == MODE_PASSTHROUGH ? "passthrough" : "emulator");
    Serial.print(" paired=");
    Serial.print(padPaired ? "yes" : "no");
    Serial.print(" ap=");
    Serial.println(apSsid);
  }

  delay(2);
}

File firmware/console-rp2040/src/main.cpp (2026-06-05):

#include <Arduino.h>
#include <Adafruit_TinyUSB.h>
#include <Adafruit_NeoPixel.h>
#include <Updater.h>
#include <cstdarg>

#include "link_protocol.h"
#include "fw_header.h"

// Non-const so the linker places this string in the .data segment,
// making it scannable in the binary image for OTA target validation.
static const char kFwIdent[] __attribute__((used)) = FW_IDENT_STR;

// Forward declarations
static void debugPrintf(const char* fmt, ...);
static bool sendFrameUart(uint8_t type, const uint8_t* payload, uint8_t payloadLen,
                          uint8_t forceSeq = 0xff);

// RP2040 role:
// 1) Receive framed events from console ESP32 over UART.
// 2) Feed Toy Pad USB emulation state machine.
//
// This starter prints incoming bytes and sets up structure for USB integration.

static const uint32_t kUartBaud = 115200;
static const uint32_t kHelloMs = 4000;
static const uint32_t kStateSyncMs = 1000;  // full-state broadcast interval

// ─── DFU / OTA state ───────────────────────────────────────────────────────────
static const uint16_t kDfuChunkMax  = 1024;
static const uint8_t  kDfuAckByte   = 0x06;
static const uint8_t  kDfuNakByte   = 0x15;
static const uint32_t kDfuTimeoutMs = 10000;  // abort DFU if no chunk for 10 s

static bool     sDfuActive     = false;
static uint32_t sDfuSize       = 0;
static uint32_t sDfuReceived   = 0;
static uint32_t sDfuLastRxMs   = 0;
static uint8_t  sDfuRxBuf[8 + kDfuChunkMax + 2];  // header(8) + data + crc(2)
static uint16_t sDfuRxIdx      = 0;
static uint16_t sDfuRxExpected = 0;
static const uint8_t kToyPacketSize = 32;
static const uint8_t kToyMagicHostToPortal = 0x55;
static const uint8_t kToyMagicPortalEvent = 0x56;
static const uint8_t kToyTagEventPayloadSize = 0x0b;
static const uint8_t kToyTagActionPlaced = 0x00;
static const uint8_t kToyTagActionRemoved = 0x01;
static const uint8_t kToyUidSize = 7;
static const uint8_t kToyInQueueSize = 8;
static const uint8_t kToyUsbReportSize = 32;

// RPCS3 Dimensions.cpp COMMAND_KEY — used as TEA key for B1/B3 auth.
static const uint8_t kCommandKey[16] = {
  0x55, 0xFE, 0xF6, 0xB0, 0x62, 0xBF, 0x0B, 0x41,
  0xC9, 0xB3, 0x7C, 0xB4, 0x97, 0x3E, 0x29, 0x7B,
};

// TEA decrypt: 8 bytes in, 8 bytes out, 32 rounds, key = kCommandKey.
// Matches RPCS3 Dimensions.cpp decrypt() with key == std::nullopt.
static void teaDecrypt(const uint8_t* in, uint8_t* out) {
  static const uint32_t kDelta = 0x9E3779B9u;
  uint32_t v0 = (uint32_t)in[0] | ((uint32_t)in[1] << 8) |
                ((uint32_t)in[2] << 16) | ((uint32_t)in[3] << 24);
  uint32_t v1 = (uint32_t)in[4] | ((uint32_t)in[5] << 8) |
                ((uint32_t)in[6] << 16) | ((uint32_t)in[7] << 24);
  uint32_t k0 = (uint32_t)kCommandKey[0]  | ((uint32_t)kCommandKey[1]  << 8) |
                ((uint32_t)kCommandKey[2]  << 16) | ((uint32_t)kCommandKey[3]  << 24);
  uint32_t k1 = (uint32_t)kCommandKey[4]  | ((uint32_t)kCommandKey[5]  << 8) |
                ((uint32_t)kCommandKey[6]  << 16) | ((uint32_t)kCommandKey[7]  << 24);
  uint32_t k2 = (uint32_t)kCommandKey[8]  | ((uint32_t)kCommandKey[9]  << 8) |
                ((uint32_t)kCommandKey[10] << 16) | ((uint32_t)kCommandKey[11] << 24);
  uint32_t k3 = (uint32_t)kCommandKey[12] | ((uint32_t)kCommandKey[13] << 8) |
                ((uint32_t)kCommandKey[14] << 16) | ((uint32_t)kCommandKey[15] << 24);
  uint32_t sum = kDelta * 32u;  // = 0xC6EF3720
  for (int i = 0; i < 32; i++) {
    v1 -= (((v0 << 4) + k2) ^ (v0 + sum) ^ ((v0 >> 5) + k3));
    v0 -= (((v1 << 4) + k0) ^ (v1 + sum) ^ ((v1 >> 5) + k1));
    sum -= kDelta;
  }
  out[0] = (uint8_t)(v0);        out[1] = (uint8_t)(v0 >> 8);
  out[2] = (uint8_t)(v0 >> 16);  out[3] = (uint8_t)(v0 >> 24);
  out[4] = (uint8_t)(v1);        out[5] = (uint8_t)(v1 >> 8);
  out[6] = (uint8_t)(v1 >> 16);  out[7] = (uint8_t)(v1 >> 24);
}

// TEA encrypt: 8 bytes in, 8 bytes out, 32 rounds, key = kCommandKey.
static void teaEncrypt(const uint8_t* in, uint8_t* out) {
  static const uint32_t kDelta = 0x9E3779B9u;
  uint32_t v0 = (uint32_t)in[0] | ((uint32_t)in[1] << 8) |
                ((uint32_t)in[2] << 16) | ((uint32_t)in[3] << 24);
  uint32_t v1 = (uint32_t)in[4] | ((uint32_t)in[5] << 8) |
                ((uint32_t)in[6] << 16) | ((uint32_t)in[7] << 24);
  uint32_t k0 = (uint32_t)kCommandKey[0]  | ((uint32_t)kCommandKey[1]  << 8) |
                ((uint32_t)kCommandKey[2]  << 16) | ((uint32_t)kCommandKey[3]  << 24);
  uint32_t k1 = (uint32_t)kCommandKey[4]  | ((uint32_t)kCommandKey[5]  << 8) |
                ((uint32_t)kCommandKey[6]  << 16) | ((uint32_t)kCommandKey[7]  << 24);
  uint32_t k2 = (uint32_t)kCommandKey[8]  | ((uint32_t)kCommandKey[9]  << 8) |
                ((uint32_t)kCommandKey[10] << 16) | ((uint32_t)kCommandKey[11] << 24);
  uint32_t k3 = (uint32_t)kCommandKey[12] | ((uint32_t)kCommandKey[13] << 8) |
                ((uint32_t)kCommandKey[14] << 16) | ((uint32_t)kCommandKey[15] << 24);
  uint32_t sum = 0;
  for (int i = 0; i < 32; i++) {
    sum += kDelta;
    v0 += (((v1 << 4) + k0) ^ (v1 + sum) ^ ((v1 >> 5) + k1));
    v1 += (((v0 << 4) + k2) ^ (v0 + sum) ^ ((v0 >> 5) + k3));
  }
  out[0] = (uint8_t)(v0);        out[1] = (uint8_t)(v0 >> 8);
  out[2] = (uint8_t)(v0 >> 16);  out[3] = (uint8_t)(v0 >> 24);
  out[4] = (uint8_t)(v1);        out[5] = (uint8_t)(v1 >> 8);
  out[6] = (uint8_t)(v1 >> 16);  out[7] = (uint8_t)(v1 >> 24);
}

// Bob Jenkins' small PRNG — matches RPCS3 Dimensions.cpp initialize_rng/get_next.
static uint32_t rngA, rngB, rngC, rngD;

static uint32_t rngRotl32(uint32_t x, int r) {
  return (x << r) | (x >> (32 - r));
}

static uint32_t rngGetNext() {
  uint32_t e = rngA - rngRotl32(rngB, 21);
  rngA = rngB ^ rngRotl32(rngC, 19);
  rngB = rngC + rngRotl32(rngD, 6);
  rngC = rngD + e;
  rngD = e + rngA;
  return rngD;
}

static void rngInit(uint32_t seed) {
  rngA = 0xF1EA5EEDu;
  rngB = seed;
  rngC = seed;
  rngD = seed;
  for (int i = 0; i < 42; i++) {
    rngGetNext();
  }
}

// Observed startup payload returned by a real Toy Pad after B0.
static const uint8_t kToyB0ReplyPayload[] = {
  0x00, 0x2f, 0x02, 0x01, 0x02, 0x02, 0x04, 0x02,
  0xf5, 0x00, 0x19, 0x8d, 0x54, 0x8e, 0x2d, 0x5b,
  0xae, 0x4e, 0x00, 0x42, 0x17, 0x01, 0x00, 0x15,
};

static const uint16_t kUsbVid = 0x0e6f;
static const uint16_t kUsbPid = 0x0241;
static const char* kUsbManufacturer = "PDP LIMITED. ";
static const char* kUsbProduct = "LEGO READER V2.10";
static const char* kUsbSerial = "P.D.P.000000";

static const uint16_t kXboxVid = 0x24c6;
static const uint16_t kXboxPid = 0xfa01;
static const char* kXboxManufacturer = "Warner Bros.";
static const char* kXboxProduct = "LEGO(R) DIMENSIONS(TM)";
static const char* kXboxSerial = "B61D757F";

// XSM3 security string — confirmed at string index 4 on real Xbox 360 Toy Pad hardware.
static const char kXsm3String[] =
    "Xbox Security Method 3, Version 1.00, \xc2\xa9 2005 Microsoft Corporation. All rights reserved.";
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

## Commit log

2026-05-10 Started work on the Wireless TP, and debugging
2026-05-21 Wireless TP working, toys not matching list yet
2026-05-21 Reading of Toys is working :).. still stuff missing
    [main.cpp]
2026-05-22 VirtualPad Correct, PhysicalPad Correct IDs, but wrong zones
    [main.cpp]
2026-05-22 VirtualPad Correct, PhysicalPad Correct IDs, zones seem ok
    [main.cpp]
2026-05-22 VirtualPad Correct, PhysicalPad Correct IDs, zones seem ok, vehicles missing
    [main.cpp]
2026-05-24 Slots are disappearing, when toy is moved
2026-05-24 v0.1: wireless toypad emulator feature complete
    - console-esp32: WiFi AP, TCP server, web UI with zone-position labels (L1/L2/L3,
    C, R1/R2/R3), LED forwarding, toy management
    - pad-esp32: USB OTG host for physical toypad, NFC UID read, zone-move with slot
    reassignment (frees old slot so vacated zone accepts full complement of toys),
    3 s move-grace window, kMoveGraceMs=3000
    - console-rp2040: USB HID device emulating LEGO Dimensions toypad, slot-independent
    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
    [Wireless Toypad Dongle v1.stl, Wireless Toypad Dongle v2 - Bottom.stl, Wireless Toypad Dongle v2 - Top.stl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]
2026-05-28 feat: OTA update system + firmware version display + binary validation
    - Add OTA endpoints to console-esp32: upload-rp2040, upload-pad, upload-console
    - Stream RP2040 firmware via UART DFU protocol (chunked with CRC16 + ACK/NAK)
    - Trigger pad OTA via LP_MSG_OTA_BEGIN over TCP; pad fetches via HTTPUpdate
    - RP2040 DFU state machine: receives OTA_BEGIN, streams chunks, commits on OTA_COMMIT
    - Add LP_MSG_OTA_BEGIN and LP_MSG_OTA_COMMIT to link_protocol.h
    - Embed FIRMWARE_VERSION (from version.txt) and FW_TARGET in every binary
    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
2026-05-28 Added New STLs and common firmware update
    [Plate for Old outlet v1.stl, Wireless Toypad v3.stl]
2026-05-28 feat: add OTA upload forms to web portal
    Each firmware target now has a file picker and Flash button in the
    Firmware Versions panel. Uploads use fetch() and display the server
    response inline (green on success, red on error). The console button
    is styled purple to hint that it triggers a reboot.
    [main.cpp]
2026-05-28 ci: ship all firmware as raw .bin, drop .gz and .uf2
    All three targets are now plain .bin files — consistent with each other
    and directly uploadable via the web UI Flash buttons without any prior
    decompression step.
2026-05-28 ui: replace bare file inputs with large tappable label+hidden-input
    Native <input type=file> widgets are tiny on mobile browsers. Wrapping
    each in a <label> makes the entire button-sized area the tap target.
    The span inside updates with the chosen filename. The Flash button and
    flashFirmware() JS are unchanged.
    [main.cpp]
2026-05-28 fix: ensure kFwIdent survives linker --gc-sections
    __attribute__((used)) alone does not prevent linker dead-section removal.
    Referencing kFwIdent in Serial.println() at boot makes the symbol
    reachable from live code, so --gc-sections keeps the section.
    Also promotes kFwIdent to 'const' now that __attribute__((used)) is kept.
    [main.cpp]
2026-05-29 fix: shorten DHCP lease time to 2 min to prevent pool exhaustion
    The ESP32 SoftAP DHCP server has 8 lease slots and a default lease
    time of ~2 hours. Stale entries from repeated connects/reboots fill
    the table, leaving no slots for new clients.
    Setting the lease to 2 minutes via esp_netif_dhcps_option ensures
    slots are freed quickly after a client disconnects.
    [main.cpp]
2026-05-29 ci: version-stamp firmware filenames and inject version from git tag
    - Firmware files are now named console-esp32-X.Y.Z.bin etc. on tag
    builds, or console-esp32-<sha>.bin on PR/branch builds.
    - set_version_flag.py prefers the FIRMWARE_VERSION env var (set by CI
    from the git tag) over version.txt, so embedded version strings also
    match the release tag.
    - manifest.json files list updated to reflect versioned names.
2026-05-29 fix: report rp2040 OTA result to browser instead of early 200 response
    [main.cpp]
2026-05-29 fix: reliably embed firmware version via generated src/firmware_version.h
    CPPDEFINES injection via extra_script doesn't trigger SCons cache
    invalidation when only the define value changes (no source file change).
    Fix: write firmware_version.h into each target's src/ directory, which
    is already on the -Isrc include path and tracked by SCons as a real
    file dependency. Any version change now triggers recompilation without
    needing a clean build.
    - set_version_flag.py: write src/firmware_version.h instead of CPPDEFINES
    - shared/include/firmware_version.h: IDE fallback stub (guarded #ifndef)
    - shared/include/fw_header.h: #include <firmware_version.h> with fallback
    - .gitignore: exclude generated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
    [set_version_flag.py]
2026-05-29 debug: add serial logging to pad OTA upload handler
    Helps diagnose silent failures: logs start/end of upload,
    LittleFS errors, chip-ID/magic-check rejections, and TCP send.
    [main.cpp]
2026-05-29 fix(rp2040): add 512KB LittleFS partition for OTA staging
    arduino-pico 4.6.0 Updater stages firmware via LittleFS (firmware.bin).
    With no FS configured the default is 0MB, making _FS_start==_FS_end,
    so Update.begin() always fails with UPDATE_ERROR_SPACE (err 4).
    512KB FS leaves 1.5MB sketch space (current binary ~131KB) with room to grow.
2026-05-29 debug: forward pad OTA errors via LP_MSG_DEBUG to console serial
    [main.cpp]
2026-05-29 fix(pad-ota): close browser connection after OTA_BEGIN response
    ESP32 WebServer holds keep-alive connections open. When handleOtaPadDone
    returns after web.send(200), port 80 is still occupied by the browser
    connection, so the pad's subsequent HTTP GET for pad-esp32.bin can't connect.
    Adding Connection:close + web.client().stop() frees port 80 immediately.
    [main.cpp]
2026-05-29 pad OTA: replace httpUpdate pull with DFU push over TCP link
    Instead of the pad fetching firmware via HTTP GET to port 80, the console
    now streams firmware directly over the existing TCP link (port 25100) using
    the same DFU chunk wire format used for RP2040 OTA:
    [0xDF][0xC0][offset LE4][clen LE2][data][crc16 LE2]
    with 0x06 ACK / 0x15 NAK responses per chunk.
    Console:
    - Remove GET /ota/pad-esp32.bin (handleOtaPadServe) — no longer needed
    - Add waitTcpAckLocal() — waits for LP ACK from pad via padClient
    - Add streamDfuToPad() — sends OTA_BEGIN, waits for ACK, streams chunks
    - handleOtaPadDone() now calls streamDfuToPad() (blocks until done,
    then returns HTTP 200/500 result to brow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
    [main.cpp]
2026-05-29 web UI: auto-reload page after successful OTA flash
    - RP2040 / pad: 2 s delay (lets user read success message), then reload
    - Console: device reboots — poll /api/state every 2 s until it responds
    (up to 30 s), then reload. Status line shows 'Waiting for device…'
    during the wait.
    [main.cpp]
2026-05-29 console-esp32: fix OTA ACK read by bypassing WiFiClient _connected cache
    waitTcpAckLocal and the DFU chunk-ACK loop both used padClient.available() /
    padClient.read(). WiFiClient::_fillBuffer() can mark _connected=false on a
    stale lwIP errno, after which available() always returns 0 even though the
    kernel socket buffer has data — exactly the same bug that made write() fail
    and was already fixed in sendFrameTcp with ::send().
    Replace both polling loops with ::recv(padClient.fd(), &b, 1, MSG_DONTWAIT):
    - waitTcpAckLocal: byte-at-a-time ::recv, feed into lp_stream_push
    - streamDfuToPad chunk-ACK loop: byte-at-a-time ::recv for 0x06/0x15 byte
    Also add an fd < 0 guard so both loops exit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
    [main.cpp]
2026-05-29 console-esp32: stream pad DFU directly during HTTP upload
    Instead of staging the binary in LittleFS and then streaming it after
    the upload completes, pipe firmware bytes directly to the pad as DFU
    chunks while the browser HTTP upload is still in progress.
    Root causes this fixes:
    1. Stale errno bug — WiFiClient::connected() does a 0-byte recv() that
    returns 0 (healthy) without clearing errno. A stale ECONNRESET from
    a prior padClient recv() caused connected() to return false, which
    made _uploadReadByte() exit and silently abort the upload.
    2. LittleFS blocking — writing 844 KB to flash took 20+ seconds
    (211 erase cycles × ~100 ms each), starving the lwIP stack and
    causin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
    [main.cpp]
2026-05-29 console-esp32: hide pad version and disable flash button when pad disconnected
    - /api/versions now includes pad_connected:true/false based on padClient.fd()
    - JS refreshVersions() shows em-dash instead of version text when disconnected
    - Pad Flash button gets id=btn-flash-pad and is disabled+greyed (opacity 0.4,
    cursor not-allowed) when pad_connected is false
2026-06-04 Updated STL
    [Wireless Toypad v4.stl]
2026-06-05 Add Xbox 360 support, RGB status LEDs, and mode button
    console-rp2040:
    - Runtime PS3/Xbox 360 profile switching via D0 GPIO (INPUT_PULLUP)
    - D1 = PS3 status LED, D2 = Xbox 360 status LED (exclusive)
    - NeoPixel: blue = PS3, green = Xbox 360
    - Xbox 360 USB identity (VID 0x24C6/PID 0xFA01, Warner Bros./LEGO DIMENSIONS)
    - Full 153-byte Xbox 360 config descriptor from real hardware
    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
